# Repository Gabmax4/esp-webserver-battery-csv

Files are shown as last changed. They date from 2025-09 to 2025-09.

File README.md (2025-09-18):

# ESP Web Server — Battery Dashboard & 25-Bay Charger

An ESP8266/ESP32 project that exposes battery telemetry via an on-device **web server**, renders a **real-time chart** in the browser (AJAX), and lets you **export CSV** for analysis.  
The repo also contains the **hardware for a 25-slot charging dock** with per-slot **CHARGE/FULL** LEDs.

Frontend lives in **`data/index.html`** (SPIFFS/LittleFS). The page polls `/battery` periodically and updates the chart; CSV can be downloaded from the same page or from a dedicated endpoint.

---

## Why it matters (OT/IoT)
- Classic **edge → UI** pattern: local telemetry, simple control, CSV export.
- Demonstrates **HTTP endpoints**, **AJAX polling**, ADC-based battery measurement, and a browser dashboard suitable for SCADA/MES-style views.

---

## Architecture

```mermaid
flowchart LR
  S[Battery/Divider -> ADC] --> M[ESP8266/ESP32 WebServer]
  M --> UI[Dashboard]
  UI --> M
  M -.-> L[LED endpoints optional]
```

---

## Features
- On-device WebServer (firmware `.ino`).
- Real-time chart (AJAX + Highcharts) from **`data/index.html`**.
- Battery endpoints and optional LED control endpoints.
- CSV export from the UI or a dedicated `/export.csv` path.
- Runs entirely on LAN (no cloud dependency).

---

## Endpoints

| Method | Path | Content-Type | Purpose |
|---:|---|---|---|
| GET | `/battery` | `application/json` (or plain text) | Returns latest battery reading (`voltage`, `percent`). |
| GET | `/export.csv`  | `text/csv` | Streams `timestamp,voltage,percent` rows. |
| GET | `/ledverde?...`, `/ledamarillo?...`, `/ledrojo?...`, `/ledblanco?...` | `text/plain` | Optional RGB controls. |
| GET | `/ledfiesta?intensidadfiesta=…&delayfiesta=…` | `text/plain` | Optional “party” mode. |

The HTML polls `/battery` every ~1s and updates the chart.

---

## Repository layout (as used here)

```
/data                                  # SPIFFS/LittleFS content served by the ESP
  index.html
/Simulacion 3D                         # Schematics, PCBs, 3D previews
/Graficas bateria/Analis de las graficas
/Datasheets
/Documentos y proveedores
/Logos
/Pulseras PCB
ESP_Grafica_WebServer.ino              # main firmware (web server + endpoints)
Lectura_Bateria.ino                    # ADC helpers (voltage/percentage)
LICENSE                                # MIT
README.md
```

> Note the folder name for charts is **Analis de las graficas** (without the second “i”). Paths below use that exact spelling and URL-encoding for spaces.

---

## Hardware — Wearable board (ESP-12F)

- **MCU:** ESP-12F / ESP8266MOD (Wi‑Fi + ADC).  
- **Regulator:** AP2112K‑3.3 LDO (ESP powered from Li‑ion).  
- **RGB LEDs:** WS281x chain (e.g., WS2812/WS2813) on a single **Data** pin.  
- **Battery measurement:** resistor divider (e.g., **R7=402k / R8=100k**) with **C5=10µF** low-pass into **ADC**.  
- **Connector:** battery input + programming pads.

**Images**

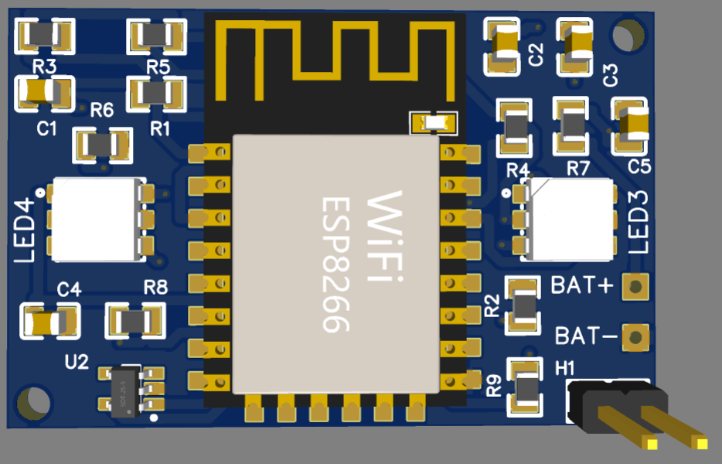
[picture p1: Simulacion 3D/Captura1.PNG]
ESP12 overview

Wearable schematic
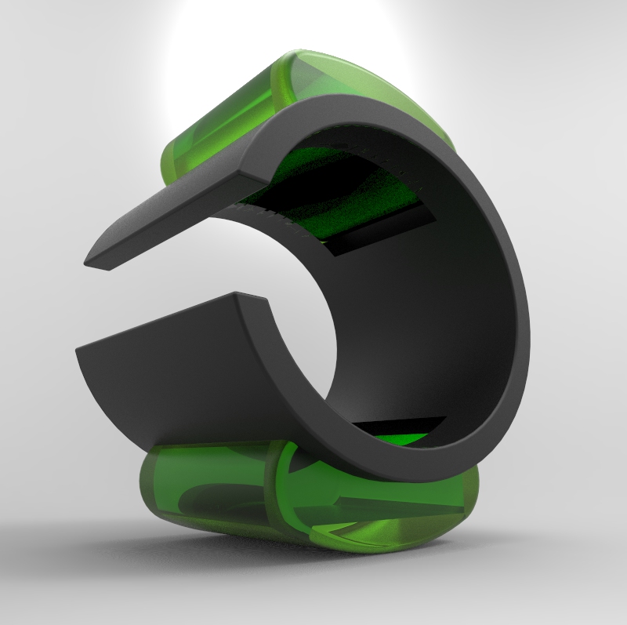
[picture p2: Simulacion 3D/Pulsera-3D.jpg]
Wearable 3D

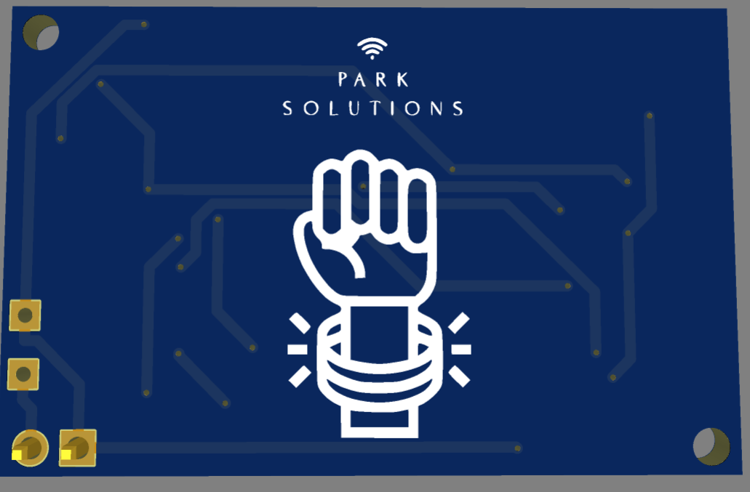
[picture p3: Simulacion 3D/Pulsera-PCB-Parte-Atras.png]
Wearable PCB back

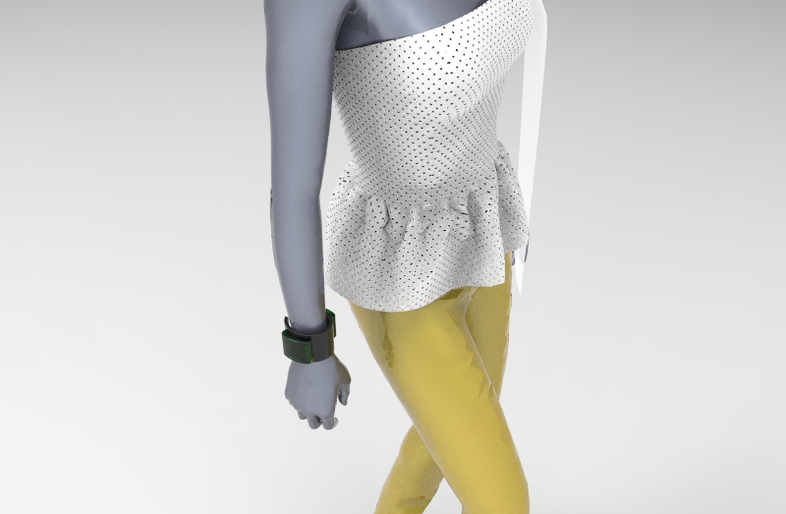
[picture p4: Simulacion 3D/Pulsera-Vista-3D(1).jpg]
3D view 1

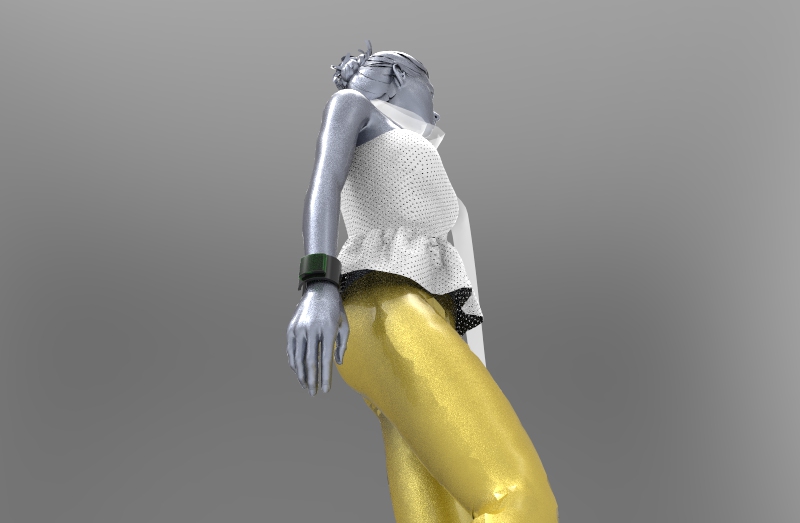
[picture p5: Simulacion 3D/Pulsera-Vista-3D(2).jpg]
3D view 2

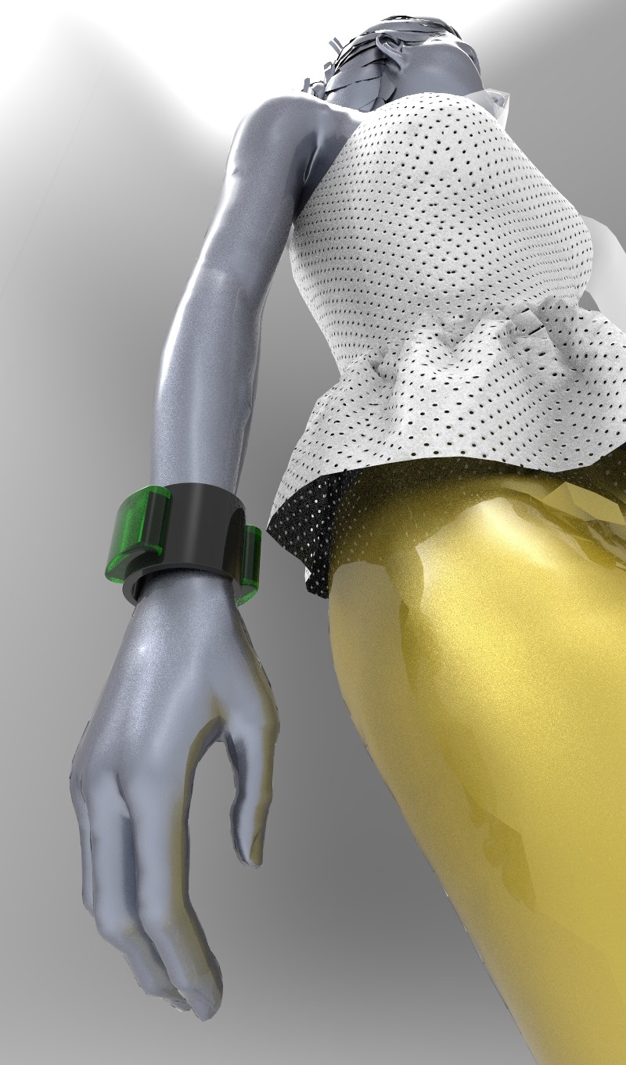
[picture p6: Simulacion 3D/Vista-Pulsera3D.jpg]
3D view 3


**Full project (schematics, PCB, BoM) on EasyEDA / OSHWLab:**  
- Wearable bracelet: https://oshwlab.com/gabmax4/pulsera-final

---

## Hardware — 25‑Bay Charging Dock

A multi‑slot charger that can **charge up to 25 bracelets simultaneously**, each slot with two status LEDs:
- **CHARGE** (charging in progress)  
- **FULL** (fully charged)

From the schematic notations, the design matches a **single‑cell Li-ion charger of the TP4056 class** (CC/CV) with a **DW01A‑class protection IC** and a **dual MOSFET pack** (e.g., FS8205A). These parts are commonly paired; if your exact IC markings differ, replace the names here with the precise part numbers from your PCB.

**Images**

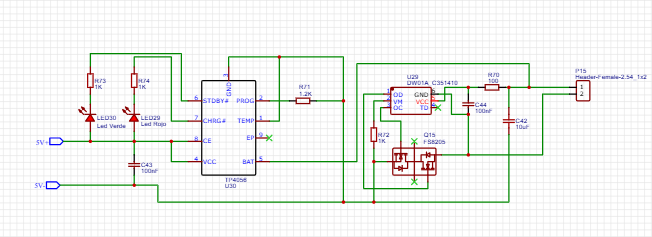
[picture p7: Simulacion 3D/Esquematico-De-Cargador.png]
Charger schematic

Charger board
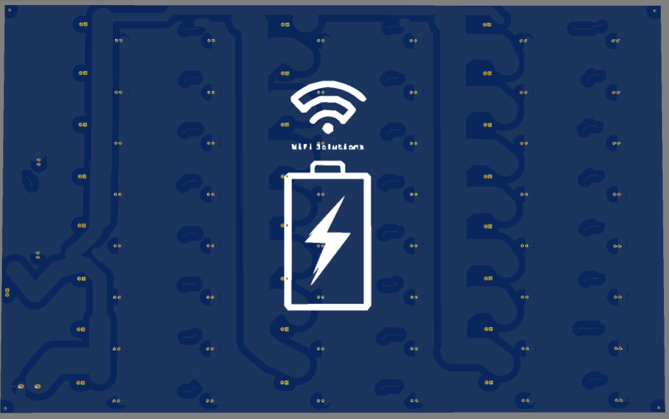
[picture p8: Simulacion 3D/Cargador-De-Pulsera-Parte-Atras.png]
Charger board back


**Full project (schematics, PCB, BoM) on EasyEDA / OSHWLab:**  
- Charger dock: https://oshwlab.com/gabmax4/cargador_pulseras

---

## Battery telemetry — Results & analysis

Live chart examples captured during testing:

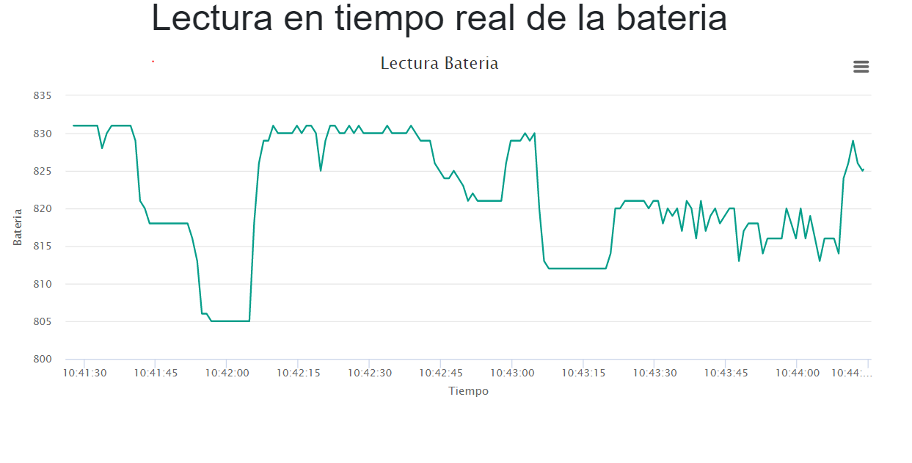
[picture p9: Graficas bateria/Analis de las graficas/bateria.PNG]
Battery live chart

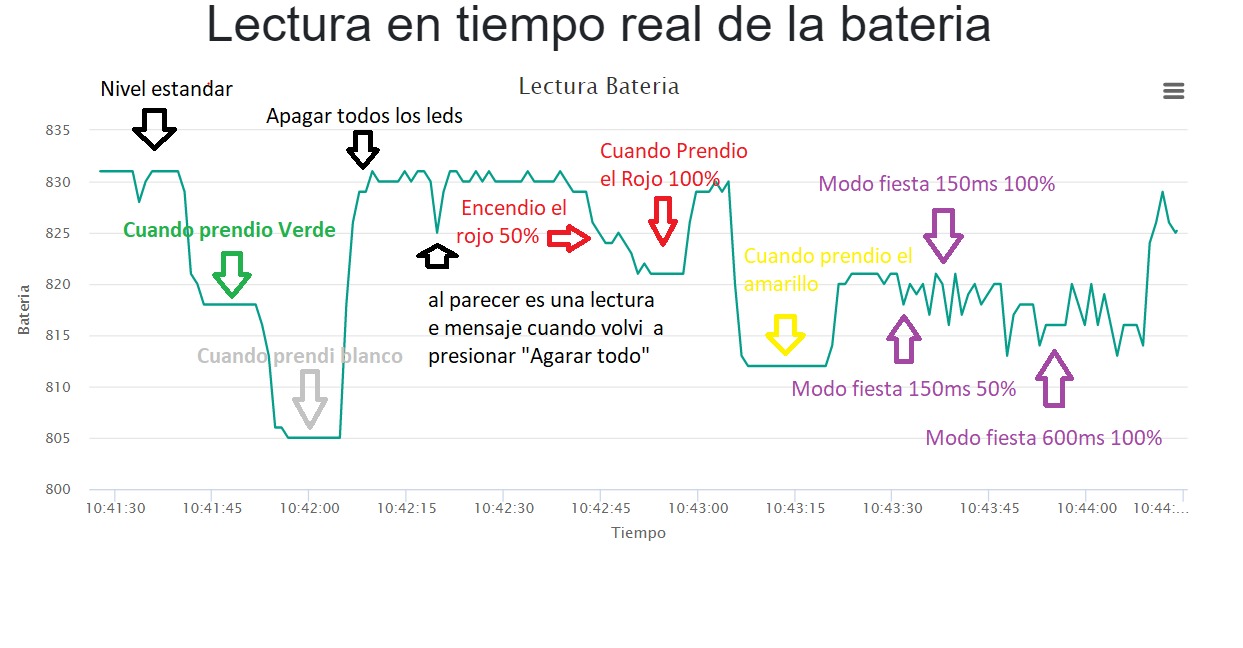
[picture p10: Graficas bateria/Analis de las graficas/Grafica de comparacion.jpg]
Annotated run


Related notes & PDF:
- Notes: `Graficas bateria/Analis de las graficas/Notas primera lectura sin grafica.txt`  
- PDF: `Graficas bateria/Analis de las graficas/lectura-bateria.pdf`

**Suggested metrics to report (fill in during a run)**
- Update latency (UI round-trip): `__ ms`  
- Dropped samples / packet loss: `__ %`  
- Voltage range & ADC scaling: `__ V` → `__ %`  
- CSV size: `__ rows` over `__ minutes`

---

## Build & upload

1. Configure Wi‑Fi in **`ESP_Grafica_WebServer.ino`**.  
2. Upload **SPIFFS/LittleFS** so **`data/index.html`** is available (Arduino/PlatformIO data upload tool).  
3. Flash the firmware.  
4. Open the device IP in a browser. The page polls **`/battery`** every ~1s and updates the chart.  
5. Download CSV from the page or via **`/export.csv`**.

---

## Security / production notes
- Add a **token/auth** if the device sits on a shared network.
- If hosting the dashboard off-device, restrict **CORS** to trusted origins.
- In OT networks, prefer network isolation/VLANs or VPN.

---

## License
Licensed under the **MIT License**. See [LICENSE](LICENSE).

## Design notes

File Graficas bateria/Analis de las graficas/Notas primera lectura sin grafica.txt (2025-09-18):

Valor lectura de la batería

ente 835 - 838 equivalieron a 4.02V midiendo mientras estaba en uso el chip!
el valor que dio cuando solo medimos la batería fue de 4.13V  sin conectarle el chip 

y los cálculos indican que como valor máximo se llega a una lectura de 875 que equivaliera aproximadamente 4.2V 
pero que este voltaje nunca es alcanzado realmente 

Ya hicimos pruebas y si se envía de manera correcta el valor de la batería

se estima que el valor de batería descargada 3.2V equivalga a 666

Con 835 equivale a 4.02V
y se midio la lectura con 4.38V  lo cual nos dio un valor analógico de 910 y eso indica que nuestras aproximaciones son correctas

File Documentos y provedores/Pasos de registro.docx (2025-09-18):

1. Llega el morro o papa y se registra
2. Se guarda en la base de datos
3. SOY SET!
4. BUSCAR SET
5. SE SELECCIONA
6. SELECCION PULSERA #X
7. MANDAR ALA PULSERA #X ESTATUS_BAT=1
8. PULSERA RESPONDE CON CARGA DE BATERIA BATTERY=%Y Y PULSERA SE EN ESPERA
9. LED=VERDE!
10. ESTATUS_LED=YA ME PRENDI WE!
11. PROCESO ALTERNO LA PULSERA LLEGA A PRENDER ROJO
12. DEVULEVEN LA PULSERA Y NOS MANDAN LED=OFF

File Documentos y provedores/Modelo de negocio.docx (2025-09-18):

Modelo de negocio

Segmento de mercado

Nuestro segmento estará dividido en dos vertientes

Niños

De entre 5 y 14 años de edad cuyos padres estén dispuestos a pagar por su diversión y entretenimiento-recreacion

Jóvenes

De entre 16 y 25 años, Cuyos padres o ellos mismos estén dispuestos a pagar por el servicio de diversión que ofreceremos el cual ningún parque de este tipo esta ofertando.

Propuesta de valor

Tres propuestas de valor son las que harán la diferencia en el lugar que las desarrollemos.

Eco parque

Un parque que no dependa de la energía suministrada por CFE, es decir el parque generara su propia energía eléctrica suficiente para suministrar la iluminación, audio, computadoras, refrigeración, etc. ¿De qué manera? a través de los saltos en los trampolines es como nosotros convertiremos ese movimiento/fuerza en energía eléctrica.

Ahorrar en energía eléctrica genera un impacto altamente efectivo y más si esa energía es generada por los mismos clientes quienes además de pagar por el uso del parque, pagan por generar la energía que este utilizamos.

Automatización

Los sistemas de control, ingresos de clientes, conteo de tiempo etc.… Incluso inventarios no tienen por qué seguir siendo análogos, ni generar una carga de trabajo y mucho menos personal innecesario.

A través de una combinación de elementos de software, crearemos una plataforma capaz de controlar el ingreso de los clientes y el tiempo que tienen para disfrutar del parque al punto de que no tenemos que revisar bitácoras sino que el mismo sistema indicara cuando el tiempo se agote así mismo el cliente se dará cuenta pues llevara una pulsera que se iluminara de cierto color cuando el tiempo este agotado, además de contar con pantallas que indicaran el tiempo que tiene cada persona, esta pulsera también servirá para acumular puntos, realizar compras y tener beneficios como, promociones, fila preferencial premios etc.. Además también se contara con una aplicación móvil en la cual se puede realizar la compra del tempo con anticipación evitar llegar a hacer fila para pagar.

Juegos e interacción virtual/física

Sabemos que es difícil que un niño hoy día salga y haga actividad física, pues este será el lugar indicado, ya que desarrollaremos Juegos que incluyan la actividad física y la implementación virtual

Todos los parques ofrecen un servicio similar trampolines), sin embargo esto hará la diferencia y atraerá más clientes además de mantener a los que tenemos y generar publicidad de boca en boca, pues sabemos que la atracción que ofreceremos será una experiencia única!

Canales de distribución

(Estrategia de introducción)

Nuestros canales de distribución con el cliente final serán de manera digital, generar un público meta y desarrollar campañas en facebook y youtube donde a través de un video publicitario mostraremos las atracciones que ofrece el parque, precios, promociones, etc.

Negociar con algunos negocios clave para que reproduzcan el video cierta cantidad de veces por cierto tiempo en sus pantallas.

Relaciones con los clientes

La relación que tendrá el personal del parque con los clientes del parque buscamos que sea de autoservicio, esta relación combina una forma más sofisticada de autoservicio con procesos automáticos.

Donde el cliente pueda apartar su lugar o realizar su compra desde antes y pagar para solamente llegar checar y comenzar a hacer uso del parque

Fuente de ingresos

La principal fuente de ingresos es la cuota por uso, es decir lo que el cliente paga por usar el parque.

¿Por que estarán dispuestos a pagar por este valor?

En primera instancia, se contara con una app donde el cliente podrá realizar su registro y comprar su tiempo anticipadamente y pagarlo.

Podrá apartar el lugar para eventos desde la app sin necesidad de ir o llamar.

No solo se contara con los trampolines, sino que dentro del parque se tendrán Juegos interactivos que combinen el uso de los trampolines y el entretenimiento virtual.

Recursos clave

Nuestros recursos importantes son todos los componentes que se utilizaran para la instalación y la puesta en marcha del sistema de generación eléctrica así como la implementación del sistema controlador.

Para la gestión de venta y juegos, nuestros recursos serán los servidores y nuestro software el cual será el punto más importante y donde más daremos peso para que funcione a la perfecciona si como la app que se desarrollara y vinculara con este sistema.

Actividades clave

Generación de energía

Atreves de los saltos en trampolines estratégicos colocaremos un mecanismo, el cual con el salto del trampolín lo convertirá en movimiento lineal para que este a través de un generador, convertirá ese movimiento en energía misma que se llevara a un inversor y después a los bancos de baterías, para que llegue a la red de CFE y suministre nuestra energía, esto claro con los parámetros establecidos por la comisión.

Punto de venta

Un punto de venta desarrollado por nosotros, el cual el cliente tendrá como control su propia pulsera la cual servirá para entrar al parque y tener el conteo de su tiempo, puntos, promociones, compras etc. partiendo de esta manera:

El cliente tendrá dos maneras de comprar tiempo para uso del parque, el podrá pagar el tiempo que desea desde la aplicación, si es un cliente nuevo, deberá realizar su registro en la aplicación y el pago, para después solo pasar al modulo de prepago a recoger la pulsera, si no lo hace a través de la aplicación, deberá llegar al modulo de registro y pago, donde se le solicitaran los datos de la persona que usara el parque: nombre, edad, domicilio del padre, aceptación de términos y condiciones.

La pulsera el cliente tendrá que devolverla al término de su tiempo esto será a la hora de su salida,

En caso de que realice el pago en línea podrá llegar, solicitar su pulsera y entrar en automático al parque solo colocando su pulsera en el lector RF-ID, el cliente puede colocar saldo a favor en su pulsera para que pueda realizar compras dentro del parque. como se manejara el tiempo? en el momento en que el cliente coloque su pulsera en el lector el tiempo comienza a correr, el cual será mostrado en las pantallas y su pulsera se iluminara de color verde mientras este dentro de su tiempo, cuando el tiempo se le termine la pulsera encenderá una luz roja indicando la finalización, así mismo esta estará vinculada al servidor el cual realizara el registro en computadora de que el tiempo ya se termino. Tmbien será mostrado en las pantallas del lugar

Por medio de la aplicación se podrá apartar el área de fiestas detallando la cantidad de personas, nombres, edades y tiempo para poder tener listas las pulseras de los que entraran al parque

El punto de venta tendrá ventajas muy variadas tales como, corte de caja, control de inventario, control de tiempos, control de empleados….

Juegos

Se instalara en dos de los trampolines grandes que están frente a la pared, dos sensores de movimiento y dos proyectores , los cuales seran para proyectar dos juegos diferentes, uno constara en tener que realizar saltos grandes para ir escalando obstáculos y recoger monedas para llegar hasta lo mas alto o lejos posible , quien llegue a lo más alto o recoja mas monedas se le generaran puntos en su usuario los cuales podrá cambiar por tiempo o productos, otro de los juegos consistirá en ir esquivando obstáculos con los brincos y tomar objetos valiosos que de igual manera el que llegue más lejos y consiga mas objetos generara puntos y beneficios

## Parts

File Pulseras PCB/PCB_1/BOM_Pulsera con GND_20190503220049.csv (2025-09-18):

ID | Name | Designator | Footprint | Quantity | Manufacturer Part | Manufacturer | Supplier | Supplier Part | LCSC Assembly | LCSC
1 | 16MHz | X1,X2 | HC-49SMD | 2 | X49SSM16MSD2SI | YXC | LCSC | C96138
2 | 22pF | C5,C6,C7,C1 | 0402' | 4 | 0402CG220J500NT | FH | LCSC | C1555 | Yes
3 | 2.2nF | C2 | 0402' | 1 | 0402B222K500NT | FH | LCSC | C1531 | Yes
4 | 4.7pF | C3 | 0402' | 1 | GJM1555C1H4R7CB01D | MuRata | LCSC | C85883
5 | 1.5pF | C4 | 0402' | 1 | GJM1555C1H1R5BB01D | MuRata | LCSC | C76900
6 | 1pF | C8 | 0402' | 1 | GJM1555C1H1R0BB01D | MuRata | LCSC | C76898
7 | 33nF | C9 | 0402' | 1 | GRM155R71E333KA88D | MuRata | LCSC | C77016
8 | 1nF | C10 | 0402' | 1 | CL05B102KB5NNNC | SAMSUNG | LCSC | C14442
9 | 10nF | C11 | 0402' | 1 | GRM155R71H103KA88D | MuRata | LCSC | C77019
10 | 8.2nH | L1 | 0402' | 1 | SDCL1005C8N2JTDF | Sunlord | LCSC | C16208 | Yes
11 | 2.7nH | L2 | 0402' | 1 | SDCL1005C2N7STDF | Sunlord | LCSC | C27123 | Yes
12 | 3.9nH | L3 | 0402' | 1 | SDCL1005C3N9STDF | Sunlord | LCSC | C14033 | Yes
13 | 1MΩ | R1 | 0402' | 1 | RC0402FR-071ML | Yageo | Mouser | 603-RC0402FR-071ML | Yes | C25879
14 | 22K | R2 | 0402' | 1 | 0402WGJ0223TCE | UniOhm | LCSC | C25547
15 | nRF24L01-REEL | U3 | QFN-20_4X4X05P | 1 | nRF24L01-REEL | NORDIC | LCSC | C93664
16 | 10K | R3,R4 | 0402' | 2 | 0402WGJ0103TCE | UniOhm | LCSC | C25531
17 | 10uF | C12 | SMD,4X5.4MM | 1 | EEE1EA100WR | PANASONIC | LCSC | C178501
18 | 100nF | C13 | 0402' | 1 | GRM155R61C104KA88D | MuRata | LCSC | C77005
19 | SMD 5050 RGB (B-R-G) | L4 | SMD 5050 RGB | 1 | SMD 5050 RGB
20 | ATMEGA8L-8AU | U2 | TQFP-32_7X7X08P | 1 | ATMEGA8L-8AU | MICROCHIP | LCSC | C9755
21 | 1N4004W | D1,D2 | DIODE_SOD-123FL | 2 | 1N4004W | Jingdao | LCSC | C162734 | Yes
22 | Header-Male-2.54_1x1 | BAT+,BAT-,VCC-FTDA,DTR,RX,TX,GND-FTDA | HDR-1X1/2.54 | 7 | Header-Male-2.54_1x1 | ReliaPro | LCSC | C81276
23 | WiFi Antena | A1 | WIFI ANTENA | 1 | New SchematicLib

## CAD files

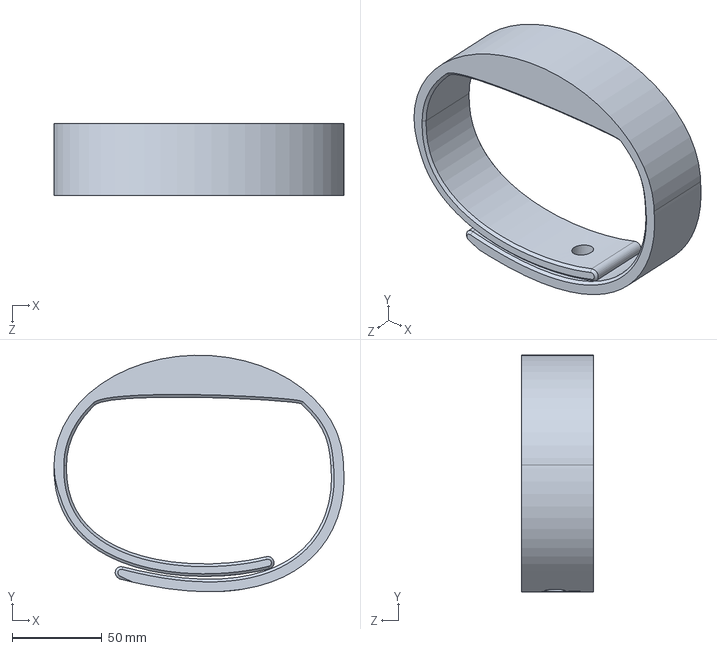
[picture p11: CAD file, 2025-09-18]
Pulseras PCB/Pulcera 1.SLDPRT
161.7 x 131.9 x 40.0 mm

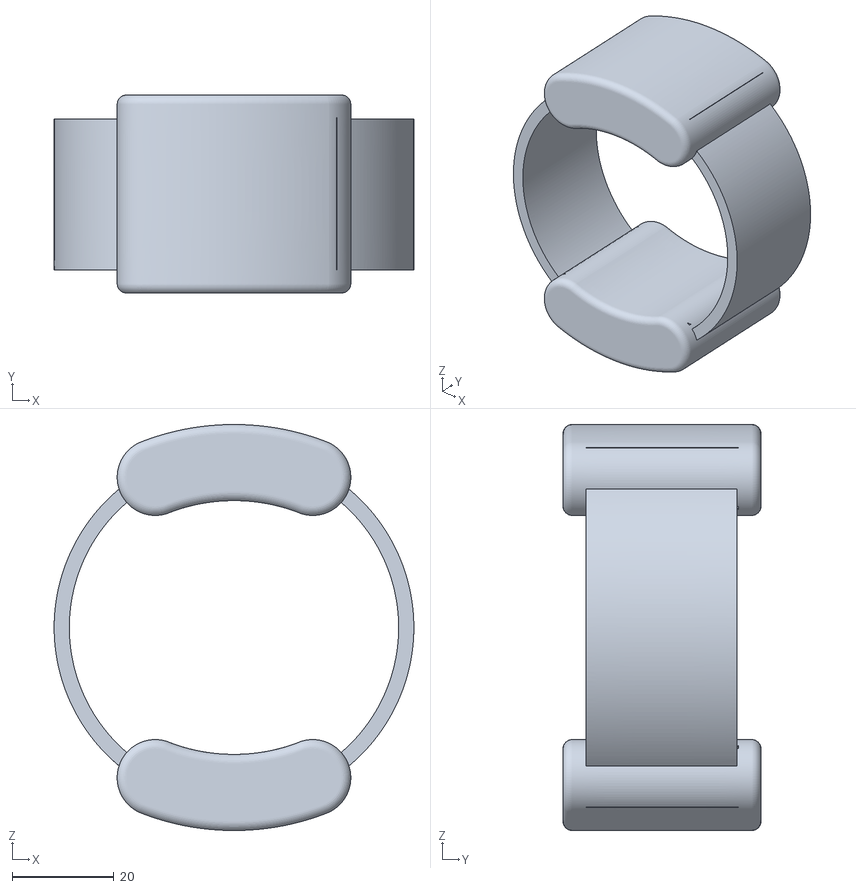
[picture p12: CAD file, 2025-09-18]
Simulacion 3D/Pulsera-3D.stl
70.9 x 39.0 x 80.0

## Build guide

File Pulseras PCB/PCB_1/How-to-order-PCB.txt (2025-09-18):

How to Order PCB

Please refer to:
https://docs.easyeda.com/en/PCB/Order-PCB

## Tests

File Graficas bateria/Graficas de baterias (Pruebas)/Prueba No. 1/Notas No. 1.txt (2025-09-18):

Esta Prueba fue grafica echa con los led blancos a 255

-Al principio de la prueba empezo a un nivel normal empezo a un nivel de 766 unidades La bateria no estaba totalmente cargad
asi que no se puede definir este como el nivel maximo de carga

-despues encendi los leds y al parecer la bateria o la pulsera tiene una ligero corto o mal funcionamiento esto lo note
por que al mover un cable tal vez hizo corto y empezo a funcionar mal devido a esto vi como el consumo de la bateria era exesivo
y se vio una caido muy intensa cuando prendi los led bloncos a maxima potencia 

*al parecer el nivel de minimo funionamiento cuando empezo a solo prender el rojo y dejo de prenderse blanco fue a un valor cercano
a los 610 unidades

-volvi a conectar la pulsera y parecia ser que todo marchaba bien asi que volivi a encender los led blancos a maxima intensidad 
justo a las 12:00 y me dio una lectura de 712 unidades al cabo de 15 minutos 12:15 la medicion fue 705.

12:00 - 712 
12:15 - 705
12:30 - 697
12:45 - 689
13:00 - 680
13:15 - 673
13:30 - 665
13:45 - 658
14:00 - 654
14:11 - 652

7-8-8-9-7-8-7-4 *2   EStos numeros son la diferencia que hay entre cada medida como se puede obrevar los que mas se repiten 
es el 8 y el 7 el 2 es una medida que no entro dentoro del estandar de 15 min si se divide 8 o 7 unidades por los 15 minutos
nos da que por cada minuto que pasa se consumenen entre 0.533 y 0.466 unidades 

entonces si 712 es la medida del 100% y 610 0% la diferencia de unidades entre los dos son 102
si cada munito equivale a 0.533 o 0.466 y dividimos 102/0.533 o 102/0.466
se estima que la pulsera dure  ente 3h con 12min y 3h con 38min 

claro teniendo en cuenta que la grafica es lineal 

prueba echa el 16/11/2020

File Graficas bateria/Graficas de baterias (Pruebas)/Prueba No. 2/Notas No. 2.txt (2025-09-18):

Esta prueba fue echa con los led blancos a 255

Estas lecturas fueron hechas mientras pasaba algo raro con la bateria ya que el cargador el cual
utilice prendian los dos focos envez de prender solo uno y a revisar note que se quedo en un valor
alrededor de 3.6V lo cual vi como un problema ya que no pasaba de esa brecha pero corri la prueba con ese voltaje 
y obtuve que cuando lo conecte bajo el voltaje de 3.6V a 3.1V y en la grafica nos daba un valor de 645 unidades 
segun los resultados de las "Notas primera lectura sin graficar" deduje que

835 = 4.02V
875 = 4.20V
910 = 4.38V
666 = 3.20V   //Estimado con el cual ya no deberia de funcionar el sistema 

COMPARACION DE RESULTADOS CON LOS PRIMEROS RESULTADOS LEIDO EN LAS PRUEBAS

En esta ocacion obtuve estas lecturas al medir con el multimetro y ver la grafica 

645 = 3.1V
606 = 2.9V

teniendo en cuenta esto confirmaremos que los calculos de "Notas primera lectura sin graficar" sean correctas solo para validar

si 			835 = 4.02V
entonces cuanto es...	645 = ?			hacemos una regla de 3 y nos da que

			645 = 3.1052V		exactamente la medida que medimos con el multimetro

confirmacion #2 

			835 = 4.02V
			606 = ?

			606 = 2.9175V		medicion casi exacta que la que medimos que fue 2.90V
al ver que todo esta correcto podemos confiar en las mediciones de unidades desconocidas a unidades de voltaje 
en futuras notas

MEDICIONES OBTENIDAS DE LA GRAFICA

me espere unos minutos para poder prender los led a maxima potencia me espera a que fueran las 4:15 para que empezara acorde con las 
mediciones de cada 15 min, la medicion que daba sin prender los led era 649 = 3.12V (aproximados/no medidos calculados) mediciones 
obtenidas:

4:15 = 610 = 2.93V
4:30 = 566 = 2.72V

solo duro prendido la luz blanca durante 19 min por lo cual solo tenemos una comparacion y como vemos esta diferencia es mayo 
que la medida en "Notas No.1" la cual era alrededor de 7 o 8 unidades en este caso son 44 unidades lo cual equivale a 0.21V la
cual es la diferencia que vemos entre  2.93V y 2.72V

cada unidad de equivale a 0.0048V esa es la presision de nuestra lectura tambien o 4.8uV (micro volts)
 
NOTA IMPORTANTE: como se estimo con anterioridad parace ser que la medida de 3.2v era lo menos con que podia funcionar la pulsera
estaba erroneo puesto que hoy confirmamos que pudo funcionar con la luz blanca prendida hasta aproximadamente valores cercanos a
550 y 555 unidades (puede ser una opcion que no halla distingido entre un 100% de intensidad pero a mi perspectiva se veia bien e
intenso como si fuera el 100%) depues de este numero medido que en voltaje equivale entre 2.64V y 2.67V. Cuando llego a el valor de 
543 = 2.61V dejo de mandar datos a la grafica se encendio los led rojos pero con muy baja intensidad duraron unos minutos y se apago
al ver que no prendia hice una ultima medicion con el multimetro y logre captar 1.68V aproximadamente 

estas notas y pruebas fueron echas el 17/11/2020

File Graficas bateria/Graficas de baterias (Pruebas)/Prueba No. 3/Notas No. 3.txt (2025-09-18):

Esta prueba fue corrida con los leds blancos a 255

empezamos la prueba con un valor de 3.72V sin conectar la pulsera una vez conecte la pulsera obtuve un valor de 3.49V depues prendi los 
leds blancos y volvi a medir y note que bajo a un valor de haste 3.26V en esta prueba al cabo de 30min se me apago la computadora y tube
que dar esta prueba como un fracaso y volverla a intentar un punto que vi fue que cuando estaba en el valor de 3.0V o 2.99 que medi con el
multimetro decidi desconectarlo y vi como el voltaje aumento a 3.44V

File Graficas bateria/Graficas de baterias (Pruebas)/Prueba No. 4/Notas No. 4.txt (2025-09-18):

Esta prueba fue echa con los led blancos a 255

Antes de conectar la bateria a la pulsera leei con el multimetro 3.70V y cunado lo conecte vi que bajo a 3.49V pero 
todabia no mandaba señal a la computadora, al momento que empece a mandar datos volvi a hacer una medicion y vi que el voltaje
seguia siendo 3.49V. Cuando prendi el led blanco el voltaje bajo hasta 3.28V osea que las diferencias se voltaje fue

-CALCULOS DE PORCENTAJES

Cuando conecte la bateria 0.21V respecto a 3.70V
Cuando prendi el led fue de 0.42 respecto a 3.7V
y respecto a 3.49 bajo 0.21V

si tomamos en cuenta que 4.2V es el 100%
y 0V el 0% tenemos que
0.21V es el 5% y 0.42V 10%

pero si tomamos 4.2V como el 100% 
y 3V como el 0% nos da que 
0.21V es el 17.5% y 0.42V 35%
del porcentaje de la bateria

pero si ponemos el valor cuando dejo de mandar datos respecto a "Notas No. 2" veremos que
si 4.2V es el 100%
y 2.61V es el 0% tenemos que 
0.21V es el 13.2% y 0.42V es 26.4%

al inicio de la prubea se tenia una memdida de 729 unidades sin prender la luz blanca 
729 = 3.50V
cuando se encendieron los led blancos bajo a 
682 = 3.28V

-MEDICIONES DE CADA 15MIN

a continuacion las lecturas de cada 15 min

3:55 = 682 = 3.28V
4:20 = 672 = 3.23V
4:35 = 663 = 3.19V
4:50 = 662 = 3.18V
5:05 = 658 = 3.16V
5:20 = 654 = 3.14V

10-9-1-4-4 diferencias entre mediciones 

empezando desde las 5:25 (Que es igual a un valor entre 652 y 649 que son aproxiamdamente entre ) emezo a haber fluctuaciones entre 28 
y  hasta 90 unidades

5:35 = aproximado 630 = 3.03V
5:50 = aproximado 618 = 2.97V
6:05 = aproximado 601 = 2.89V
6:20 = aproximado 596 = 2.86V
6:35 = aproximado 592 = 2.85V
6:50 = aproximado 596 = 2.86V
7:05 = aproximad0 601 = 2.89V
7:20 = aproximado 585 = 2.81V
7:35 = aproximado 576 = 2.77V
7:50 = aproximado 575 = 2.76V
8:05 = aproximado 570 = 2.74V
8:20 = aproximado 530 = 2.55V
8:30 = aproximado 512 = 2.46V     (ultima medicion)

12-17-5-4-(-4)-(-5)-16-9-1-5-40-18  Difrencia entre mediciones

el valor mas bajo medido fue 498 = 2.39V a la hora de 8:15:33

-CONCLUSIONES			

en esta grafica como vemos la grafica no parece ser lineal como en el caso de la grafia de las "Notas No. 1" donde teniamos claro
que proximadamente se bajaban entre 7 y 8 unidades por cada 15 minutos al ver esta grafica no parece ser linetal y esto puede ser
devido a que la bateria ya esta cada vez mas estropeada lo cual hace que no sea algo linea, esta vez obtuvimos una medicion aun
menor que las tomadas en las "Notas No. 2" que fue de 543 = 2.61V esta vez obtuvimos un valor de 498 = 3.39V pero cuando dio este
valor no se apago solo fue el valor minimo leido se apago al dar la lectura de 512 = 2.46V lo cual nos dice que el margen de menor
rango de uso esta entre 543 y 498 unidades. el proyecto duro andando desde las 03:50:23 hasta las 08:30:35 esto nos da que la pulsera
estuvo en funcionamiento durante 6:20:58 (6h 20min y 58seg) esto con los led blancos prendidos antes de eso estuvo prendido durante 
5min con 21seg eso nos da en total un funcionamiento de 6h 26min y 19seg. Esto es mas de lo que se anteriormente se estimo

23/11/2020

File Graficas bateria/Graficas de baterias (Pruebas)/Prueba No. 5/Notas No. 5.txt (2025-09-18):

Esta prrueba fue corrida con el led amarillo a 255 

En "Notas No. 4" se dice que el voltaje leido sin que se conectara la bateria a la pulsera fue de 3.70V y cuando se conecto bajo a 
3.49V. En esta caso la batieria sin conectar a la pulsera dio 3.97V y conectado a la pulsera dio 3.64 tambien cuando estaba mandando
datos dio una medicion de 3.64V. a diferencias que lo que se mostro en las "Notas No. 4" se vio que el bajon de voltaje cuando se conecto
fue de 0.21V y en este caso fue de 0.33V osea que en este caso todavia bajo mucho mas que la ultima vez que se conecto la pulsera 

---------------------------CALCULOS DE CUANTO SE SUPONIDA QUE DURARIA ESTA PRUEBA CON EL AMARILLO-----------------------------------------

coomo se puede ver en la prueba pasada la bateria estaba mas cargada que esta vez a conitinuacion se muestran los calculos para saber que
tanto estaba cargada de mas respecto a la medicion anterior.

supongamos que 3.7V es el 100% para que el sobrante de 100% sea la comparativa entonces

3.70V = 100%
3.97V = ?

(3.97V)(100%)/3.70V = 107.30% redondiando 100% - 107.30% = 7.30%

ahora se hara lo mismo pero con los valores cuando se conecto la pulsera

3.49V = 100%
3.64V = ?
(3.64V)(100%)/3.49V = 104.30% redondiando 100% -104.30% = 4.30%

tomare como medida de cuanto estaba mas cargada respecto a la ultima prueba la de 4.30% por que esta medida fue realizada ya que se
conecto la bateria a la pulsera asi que se me hace una medida mas real. Ahroa como vimos en la "Pueba No. 4" duro un tiempo de 
6h 20min y 58seg para sumarle el 4.30% que nos falta tomaremos la primera parte que se ve lineal de la grafica que pueron los primeros
30min a 15min los cuales tuvieron una caida de entre 9 y 10 unidades por lo cual:

si cada 10 unidades = 15min 

ahora tenemos que determinar ese 4.30% a cuanto es equivalente yasea en unidades o en voltaje
entonces si 3.70V = 100%
	      ?   = 4.30% 

(4.30%)(3.70V)/100% = 0.1591V

ahora que sabemos el voltaje equivalente a 4.30% lo convertimos en unidades si sabemos que 
que 1 unidad = 0.0048V
	 ?   = 0.1591

(0.1591V)(1 unidades)/0.0048V = 33unidades
y estas 33 unidades en tiempo queremos saber cuando equivale por lo cual hacemos la sigueinte regla de tres

10 unidades = 15min
33 unidades = ?

(33 unidades)(15min)/10 unidades = 49min con 30seg 

------------------------------------CALCULO DE APROXIMACION DE TIEMPO ENCENDIDO DE PRUEBA NO.5-------------------------------------------

entonces suponiendo que la pila estuviera 4.30% mas cargada duraria  en cuestion aproximadamente 7h 10min y 28seg y al ver el "Grafico 
prueba" vemos que el led amarillo es aproximandamente un 75% de lo equivale el led blanco entonces hay que sumar el 25% restante para
poder hacer un aproximado de lo que durara el led amarillo y si esto es cierto podriamos llevar este calculo a las demas graficas 
para saber un aproximado de cuanto nos dara. Entonces

transformaremos todo el tiempo en segundos 
25828 seg = 100% 
    ?     = 25%
(25%)(25828seg)/100% = 6457 seg
esto es 1h 47min y 37seg claro esto es tomando en cuenta de que nuestro sistema sea lineal pero no lo es por lo cual el valor sera 
inferior a esto pero podemos darnos una proximado con estos numero. Entonces podemos aproximar que esta prueba va a durar
8h 58min 5seg

----------------------------------------------VALORES PRACTICOS---------------------------------------------------------------------------

La prueba con los leds amarillos prendidos a 255 duro 7h 12min y 58 seg y antes de prender el led amarillo dure 5min antes de prenderlo 
eso son deje que mis calculos tuvieron maregen de error de:
32285seg = 100%
25978seg = ?

(25978seg)(100%)/32285seg = 80%

ahora hacer las mediciones que se obtivieron cada 15min en la prueba:

4:00  = 710 = 3.41V
4:15  = 705 = 3.39V  (bajada extraña)
4:30  = 694 = 3.33V
4:45  = 691 = 3.32V
5:00  = 684 = 3.29V
5:15  = 680 = 3.27V
5:30  = 673 = 3.24V
5:45  = 667 = 3.21V
6:00  = 662 = 3.18V
6:15  = 655 = 3.15V
6:30  = 652 = 3.13V
6:45  = 648 = 3.11V
7:00  = 645 = 3.10V
7:15  = 643 = 3.09V
7:30  = 642 = 3.09V
7:45  = 640 = 3.08V
8:00  = 640 = 3.08V
8:15  = 639 = 3.07V
8:30  = 637 = 3.06V
8:45  = 633 = 3.04V
9:00  = 630 = 3.03V
9:15  = 628 = 3.02V
9:30  = 626 = 3.01V
9:45  = 622 = 2.99V
10:00 = 618 = 2.97V
10:15 = 615 = 2.96V
10:30 = 609 = 2.93V
10:45 = 604 = 2.90V                     (desde este punto callo como tipo exponecial mente)
11:00 = 590 = 2.84V
11:12 = 560 = 2.69V                     (ultima medicion)

5-11-3-7-4-7-6-5-7-3-4-3-2-1-2-0-1-2-4-3-2-2-4-4-3-6-5-14-30
los valores que mas se repitieron fueron 3-4-2 aproximadamente este valor equivale a 0.01V que como vemos es el valor que mas se repite
asiq ue podemos definir que cada 15 min se restaban 0.01V aproximadamente

En otras ocaciones como en caso de la prueba 4 y 2 dieron valores de desactivacion sercanos 512 y 543 en esta ocacion fue 560 el cual a
sido el valor mas alto de desactivacion que se a registrado 

NOTA: una vez que ya no mando datos instantanea mente se prendio la luz como un tipo de naranja esto se debe a que ya no fue suficiente
la energia para prende amarillo por cual las luces disminuieron su potencia y se vio un tipo de naranja supongo por que el led verde ya 
no tenia suficiente ptencia y bajo su intensisdad ya que el amarillo es una combinacion del rojo y verde y normalmente el rojo es el que
se queda prendido puesto que es el que menor cantidad de energia consume. Esto quiere decir que aun tenia mas energia que entregar pero
por alguna razon ya no pudo entablar comunicacion y mandar datos cuando esto ocurrio rapidamente hice una medicion con el multimetro
y medio valores entre 2.29V y 2.27V. ALGO IMPORTANTE fue que cuando desconecte la bateria volvi a medir con el multimetro y me dio 
entre 2.94V y 2.99V en el multimetro lo que se recomienda como el minimo de la bateria.

----------------------------------------------------------CONCLUSIONES--------------------------------------------------------------------

Al ver la grafica parece ser lineal de menos en los primeros momentos y podemos ver como justo cuando se desnecto se vio una bajada
muy pronunciada de voltaje por lo cual podemos definir ese punto como el limite de la grafica veremos en sigueintes pruebas si este 
punto es igual a los que se leeran futuramente, este punto fue aproximadamente en el 600, lo que se abia definido antes es que este 
no baje la pila del valor de 3V el cual aproximadamente equivale a 625 unidades que para que llegara a este punto en la grafica duro 
5h con 35min lo cual se me hace mas que suficiente para las demandas del proyecto. 

24/11/2020

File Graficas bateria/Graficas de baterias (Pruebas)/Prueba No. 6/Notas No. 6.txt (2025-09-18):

Esta prueba fue corrida con el led verde a 255 

A diferencia de otras pruebas en esta realice mediciones de volaje cad 15min para poder checar si mis reglas de 3 y mis calculos son
correctos. Este fue el primer caso que tue que el cargador me cargo totalmente mi bateria pero al parecer no me lo cargo totalmente
puesto que el voltaje no llego a los esperados 4.2V si no que cuando lo medi sin conectarlo a la pulsera me dio un valor de 
4.01V y cuando lo conecte a la pulsera bajo a un valor de 3.87V esto causo una caida de voltaje de 0.14V, tambien realice la lectura 
cuando estba mandando datos y fue exactamente igual que cuando se conecto la bateria a la pulsera 3.87V a continuacion analizare 
las caidas de voltaje de las anteriores pruebas para ver si existe alguna realcion y siempre es la misma.

"Notas No. 2"
3.60V a 3.10V difrencia = 0.50V

"Notas No. 3"
3.72V a 3.49V difrencia = 0.23V

"Notas No. 4"
3.70V a 3.49 difrencia = 0.21

"Notas No. 5" 
3.97V a 3.64V difrencia = 0.33

"Notas No. 6" (son estas)
4.01V a 3.87V difrencia = 0.14

todas los resultados anteriores fueron sin prender ningun led solo conectando la pulsera, creo que esto debe a que la bateria tiene una 
resistencia interna por lo cual el voltaje se ve implicado y es un poco diferente a medida que el voltaje de la fuente es diferente
puesto que esta resstencia interna tiene que mandar mas corriente o voltaje pero como vemos en el caso de Notas No.2 y No.3 el valor es 
muy parecido solo vayo por 0.02V, esto me hace que mi hipotesis que esto es por una resistencia interna sea la mas cercana a este caso
puesto que a medida que es un valor mas grande el voltaje que se quita de la fuente (bateria) es menor y a medida que es mas bajo este 
valor y corro la prueba veo que hay mas caida de voltaje por lo cual he llegado a la conclusion que entre mas cargada este la bateria
mas tiempo de vida tendra puesto que habra una descarga mas progresiva ESTO ES IMPORTANTE! Tratare de hacer pruebas con siempre el 100%
de carga segun mi cargador que al parecer ronda de los 4V hacia arriva para ver si existe alguna coinsidensia.

-------------------------------------MEDICIONES HECAS CON EL MULTIMETRO-----------------------------------------------------------------

A continuacion en esta prueba a diferencia de las otras realice mediciones con el multimetro aproximadamente cada 15min para de ese modo
ver si nuestros calculos de lo que equivale las unidades de la bateria estan bien con el valor de voltaje que creemos que nos da y si hay
un error tratar de corregir las medidas para ajustarlo y tener mas presision. A continuacion muestro mis mediciones echas con el multimetro
y cuando me marco la grafica cuando la volvi a revisar en el punto que segun yo hice la medicion por que claro puede tener margen de error

3.77V = 787 unidades = 11:15
3.73V = 778 unidades = 11:30
3.70V = 773 unidades = 11:45
3.67V = 768 unidades = 12:00
3.65V = 762 unidades = 12:15
3.63V = entre 759 y 758 = 12:30
3.61V = 754 unidades = 12:45
3.19V = 665 unidades = 19:39
2.41V = entre 506 y 501 = 20:23 (Bajon de intensidad de los leds evidente)

extra:  Justo cuando dejo de mandar datos vi como los led imediatamente se apagaron no se quedaron ensendidos como en otros casos 
y cuando trate de hacer una lectura de la vateria me marco 0V con el multimetro creo que esto es debido al circuito de proteccion
que contienen la baterias de polimero de litio entonces la carge solo 2segundos para que volviera a la vida y hice la medicion y me dio
un valor de 2.91V 

-------------------------------MEDICIONES SIN EL MULTIMETRO ----------------------------------------------------------------------------

Las sigueintes mediciones fueran las que nos dio la gracias cada 15min y en estos resultados utilizare la formula o la regla de tres 
que estaba utlizando para saber el valor de voltaje respecto de cada una de las unidades y de eso modo sabre si mi calculo esta bien
hecho en caso que no lo esto tratare de perfeccionarlo, normalmente utlizo la sigueinte igualdad 835 = 4.02V y hago la regla de tres. 

8-9-5-5-6

11:00 = 795 = 3.82V  
11:15 = 787 = 3.78V 
11:30 = 778 = 3.74V
11:45 = 773 = 3.72V  -
12:00 = 768 = 3.69V
12:15 = 762 = 3.66V
12:30 = 758 = 3.64V
12:45 = 754 = 3.63V
13:00 = 748 = 3.60V
13:15 = 744 = 3.58V
13:30 = 739 = 3.55V
13:45 = 734 = 3.53V
14:00 = 729 = 3.50V
14:15 = 726 = 3.49V
14:30 = 722 = 3.47V
14:45 = 720 = 3.46V
15:00 = 717 = 3.45V
15:15 = 716 = 3.44V
15:30 = 714 = 3.43V
15:45 = 712 = 3.42V
16:00 = 710 = 3.41V
16:15 = 709 = 3.41V
16:30 = 708 = 3.40V
16:45 = 706 = 3.39V
17:00 = 703 = 3.38V
17:15 = 702 = 3.37V
17:30 = 699 = 3.36V
17:45 = 694 = 3.34V
18:00 = 692 = 3.33V
18:15 = 689 = 3.31V
18:30 = 685 = 3.29V
18:45 = 680 = 3.27V
19:00 = 675 = 3.24V
19:15 = 673 = 3.24V
19:30 = 664 = 3.19V
19:45 = 660 = 3.17V
20:00 = 636 = 3.06V
20:15 = 589 = 2.83V
20:23 = 499 = 2.40V ULTIMO VALOR MEDIDO

ahora se comprararan las dos mediciones 
     Mediciones hechas con el multimetro         Mediciones calculadas      DIFERENCIA DE VOLTAJE
	3.77V = 787 unidades = 11:15 ------------ 11:15 = 787 = 3.7889V 		0.0189+
	3.73V = 778 unidades = 11:30 ------------ 11:30 = 778 = 3.7455V			0.0155+
	3.70V = 773 unidades = 11:45 ------------ 11:45 = 773 = 3.7215V			0.0215+
	3.67V = 768 unidades = 12:00 ------------ 12:00 = 768 = 3.6974V			0.0174+
	3.65V = 762 unidades = 12:15 ------------ 12:15 = 762 = 3.6685V			0.0185+
	3.63V = entre 759 y 758 = 12:30 --------- 12:30 = 758 = 3.6492V			0.0192+
	3.61V = 754 unidades = 12:45 ------------ 12:45 = 754 = 3.6300V			0.0200+
	3.19V = 665 unidades = 19:39 ------------ 19:39 = 665 = 3.2015V 		0.0115+
											0.0178125 Promedio

le saque la diverencia de cada uno para ver el margen de erro y como vi que 0.01 se repetia mucho tome mas decimales de los calculos
y lo promedie para poder sacar un valor un poco mas estable ahor hare los nuevos valores de voltaje utilizando la siguiente formula

((unidades que quiero convertir a voltaje)*4.02/835)-0.0178125
3.77109768       
3.727768338
3.703696482
3.679624626
3.650738398
3.631480913
3.612223428
3.183744386

con esta nueva formula se afinaron un poco mas los datos a los valores reales puesto que no cuento con un multimetro 
capas de leer muchos decimales se me es practicamente imporible poder tener mediciones mas finas puesto que no cuento con el equipo
necesario 

---------------------------CALCULOS DE CUANTO SE SUPONIDA QUE DURARIA ESTA PRUEBA CON EL VERDE-----------------------------------------

ahora lo que queremos hacer es determinar un valor teorico de cuanto se supondria que duraria la pulsera en funcionamiento como vimos en 
"Notas No. 5" el valor que dio la pila al medirla con el multimetro cuando se conecto fue de 3.64V y el de esta prueba fue de 3.87V
entonces supongamos que 3.64V es el 100% y determinemos el valor de 3.87V

3.64V = 100%
3.87V = ?

(3.87V*100%)/3.64V= 106.31% - 100% = 6.31% 

convertimos 6.31% a voltaje que es 0.23V

ahora lo convertimos a unidades 0.23V = 47 unidades aproximadamente

y unidades a tiempo utilizando los mismos calculos de las "Notas No. 5"
nos da que es equivalente a 1h con 10min y 30seg
------------------------------------CALCULO DE APROXIMACION DE TIEMPO ENCENDIDO DE PRUEBA NO.6-------------------------------------------

ahora teniendo en cuenta que cuando se hizo la prueba con losled amarillos duro 7h 12min y 58seg esto basado en las "Notas No. 5" y que 
segun la "Grafica de comparacion" en comparacion el led verde con el amarillo es la diferencia que tienen es de 1/3 o 33.33% convertire
estos valores a segundos y le sumare el 33.33% y despues le sumare el 6.31% que en si es 1h 10min 30seg

25979seg = 100%
    ?    = 133.33%

34638 seg = 9h 37min 18seg
esto mas el 6.31% que sacamos por que la pila estaba de mas cargada da 
10h 47min 30seg

----------------------------------CALCULOS CON EL VALOR RELA DEL TIEMPO QUE DURO LA PRUEBA------------------------------------------------

segun los calculos la prueba deberia de durar 10h 47min y 30seg pero el valor que de verdad duro fue 9h 23min y 52seg (5 min que no se 
prendieron los leds) que se asemeja muchisimo al valor que alculamos pero sin el 6.31% ahora sacaremos el margen de error respecto el 
margen de error fue de: 

38850seg = 100%
33832seg =  ?

esto nos da un margen de error de 12.91% 

---------------------------------------------Conclusiones--------------------------------------------------------------------------------

Un dato que fato remarcar es la MODA de la diferencia que hay entre las unidades despues de cada 15min y es de 5 unidades por lo cual esto
quiero decir que cada 15unidades tenemos un baja de 5 unidade a diferencia de la puega No. 5 se tuvo una MODA de 2,3 y 4 a continuacion 
muestro la tabla de diferencias 
8-9-5-5-6-4-4-6-4-5-5-5-3-4-2-3-1-2-2-2-1-1-2-3-1-3-5-2-3-4-5-5-2-9-4-24-47 existe 6(4), 8(5), 5(3), 7(2) y 4(1) se puede ver que los
valores mantienen una baja de entre 2 y 5 unidades que al parecer corresponde con que el valor del verde sea el 33.33% del amarillo

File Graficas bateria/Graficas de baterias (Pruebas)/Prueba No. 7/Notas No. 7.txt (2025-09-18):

Esta prueba fue corrida con el led rojo a 255 

En este caso a diferencia de lo que me salio en las "Notas No. 6" la bateria estuvo mas cargada por lo cual creo que esta vez durara un 
poco mas. La medicion que obtuve fue de 4.08V sin conectarlo a la pulsera una vez conectandolo tuve 3.95V y cuando empezo a mandar dato
bajo a 3.95V. 

------------------------------------------------VALORES DE CADA 15 MIN --------------------------------------------------------

A continuacion se muestran los valores medidos con un lapso de 15min 

Unidades      voltaje (teorico)         tiempo 

806		3.862570734V		04:25
800		3.833684506V		04:40
794		3.804798278V		04:55
786		3.766283308V		05:10
783		3.751840195V		05:25
776		3.718139596V		05:40
770		3.689253368V		05:55
765		3.665181512V		06:10
759		3.636295284V		06:25
754		3.612223428V		06:40
748		3.583337201V		06:55
745		3.568894087V		07:10
739		3.540007859V		07:25
735		3.520750374V		07:40
730		3.496678518V		07:55

En este punto se efectuo un apagon pero muy pequeño se puede ver en la grafica como un pequeño triangulo 
este apagon sucedio de las 08:05:27 a las 08:19:59 el tiempo que durante este apagon fue de 14 min con 32seg depues duro prendido durante
1min con 25seg y despues se volvio a apagar a las 08:20:34 y se prendio a las 08:20:53 osea que duro apagado durante 19seg y en total
duro apagado por 15min 51seg. Es por esta razon que las siguientes mediciones se les sumeraon 15min para hacer la medidicon mas exacta
independiendtemente del apago que ocurrio.

722		3.458163548V		08:35
722		3.458163548V		05:50
721		3.453349177V		09:05
718		3.438906063		09:20
717		3.434091692V		09:35
716		3.42927732V		09:50
712		3.410019835V		10:05
710		3.400391093V		10:20
712		3.410019835V		10:35
109		0.506953967V		10:50
708		3.39076235V		11:05
706		3.381133608V		11:20
703		3.366690494V		11:35
701		3.357061751V		11:50
696		3.332989895V		12:05
692		3.31373241V		12:20
687		3.289660554V		12:35
681		3.260774326V		12:55
680		3.255959955V		13:05
676		3.23670247V		13:20
670		3.207816243V		13:55
652		3.12115756V		13:50
607		2.904510853V		14:05
464		2.216055763V		14:17       (Ultima medicion)

NOTA IMPORTANTE: Puse una regla en la grafica para poder ver en que momento aproximadamente dejava de ser linear la caida de la carga
de la bateria y note que aproximadamente esta caida empezo en 674 al 660 que este valor en voltaje es igual a 3.227073728 y 3.15967253
despues promedie las diferencias de voltaje y de unidades y me dio en promedio cada 15min baja 4 unidades o 0.02V-

---------------------------CALCULOS DE CUANTO SE SUPONIDA QUE DURARIA ESTA PRUEBA CON EL ROJO-----------------------------------------

A continuacion realizare los debidos calculos para saber cuanto durara la pulsera prendida teoricamente y veremos cuanto no hacercamos 
al valor que queremos conseguir haciendo lo mismo que "Nota No. 6".

3.49V = 100%
3.95V = ?

dio 8.51% 

en voltaje 0.31487V
en unidades 65 
en tiempo 1h 37min 30seg

ahora teniendo en cuenta que cuando se hizo la prueba con losled amarillos duro 7h 12min y 58seg esto basado en las "Notas No. 5" y que 
segun la "Grafica de comparacion" en comparacion el led rojo con el amarillo es la diferencia que tienen es de 1/2 o 50% convertire
estos valores a segundos y le sumare el 50% y despues le sumare el 8.51% que en si es 1h 37min 30seg

25979seg = 100%
    ?    = 150% 

150% = 38,968.5seg = 10h 49min 28seg

ahora hay que sumerle el 8.15% que daria
12h 26min 58seg = 44,818seg

como en la anterior tuvimos un margen de error del 12.91% segun las "Noras No. 6" con estos datos ahora voy a sacar el 12.91% y luego 
lo restare para ver el valor teorisado 

100% = 44,818seg
12.91% = ?

12.91% = 5,786seg
5,786seg - 44,818seg = 39032seg = 10h 50min 32seg

----------------------------------------------------COMPARACION TIEMPO TEORICO CON EL REAL----------------------------------------------

el tiempo que duro la prueba fue de 10h 7min 21seg pero como hubo un apagon en un lapso de tiempo eso nos da que realmente fue de
9h 51min 30seg eso nos da un mergen de error del 

100% = 39032seg
  ?  = 35490seg
 
un hacierto del 90% el mas alto que he tenido hasta ahora 

aun que si contamos el tiempo que este duro sin prender (2min 38seg) los led el valor final se tiempo fuera  9h 54min 8seg

----------------------------------------------------CONCLUSIONES----------------------------------------------------------------------

cada vez que avanzan mas las pruebas se afina mucho mas las aproximaciones lo cual sera cricial para determinar cuanto puede durar la 
pulsera con los valores y las comparaciones hechas anteriormente. tambien cabe resaltar que todas las gracias parecen ser muy lineales
hasta un cierto punto necesitare graficas en otros programas para ver cual es este punto de caida pero al no contar con eso todavia 
lo dejare para pruebas posteriores en las pruebas del modo fiesta que sera la sigueinte pondre los valores y comparaciones de todos los
led se necesita hacer mas analisis para los datos para ver hacer suposisiones mas exactas.

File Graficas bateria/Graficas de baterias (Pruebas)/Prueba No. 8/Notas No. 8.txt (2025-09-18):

Esta prueba fue corrida con el MODO FIESTA a 255 y 50 milisegundos 

En esta prueba a diferencia de las anterirores vi que los valores fluctuaban mucho puesto que no pude hace un analisis de los datos tan
exactos como la anterior por lo cual me abstendre de hacer la prueba y ya que tenga la herramienta para graficar mejor le hare un 
analisis mas detallado al principi de la prueba isn conectar la pulsera la bateria me dio un valor al medir con el multimetro de 4.09V
y al conectarlo bajo a 3.94V y aqui fue cando ocurrio lo extraño puesto los valores empresaron fluctuar entre 3.91 y 3.88V, cuando volvi a
ver el proyecto ya se encontraba todo apagado y no logre ver ningun bajon de intensidad puesto que no lo estaba checando y cuando medi
con el multimetro em dio 0.60V y cuando desconecte la pulsera me dio 2.98V. como no tengo los otros datos solo realizare los calculos de la 
aproximacion de tiempo teorico y real, pero hay que tener en cuenta que no tomare este valor muy enserio puesto que no es una relacion
totalmente lineal y puede fluctuar demasiado 

--------------------------------------------------CALCULO TEORICO DE TIEMPO QUE DURARA LA PRUBEA-----------------------------------------

Se realizara el mismo procedimiento que las en "Notas 7" entonces teniendo en cuenta que 

3.49V = 100%
3.94V = ?

nos da 12.89%

3.70V = 100%
  ?   = 12.89%

nos da 0.47693V

que 1 unidad = 0.0048V
	 ?   = 0.47693V

nose da 99 unidades

10 unidades = 15min
99 unidades = ?

nos da 148.5min = 2h 28min 30seg

Ahora determinare cuanto tiempo durara respucto a el "Grafico de comparacion" a simple vista puedo notar que es un 60% aproximadamente
en comparacion a el led amarillo (duro 7h 12min y 58seg) entonces si es asi devemos de sumarle el 30% a lo que duro el led amarillo para ver cuanto duraria
teoricamente

25979seg = 100%
    ?    = 130% 

nos da 337723seg = 9h 22min 53seg

ahora hay que aumentar el 12.89% 

337723 + 8910 = 42683 seg = 11h 51min 23seg

como en la anterior tuvimos un margen de error del 12.91% segun las "Noras No. 6" con estos datos ahora voy a sacar el 12.91% y luego 
lo restare para ver el valor teorisado pero en "Notas No. 7" tuvomos 10% de marguen de error entonces sera un 22.92%

100%   = 42683seg
22.92% = ?

nos da 9783seg 

42683seg - 9783seg = 32900seg = 9h 8min 20seg

---------------------------------------------------COMPARACION CON VALORES REALES---------------------------------------------------------

el proyecto empezo a corer a las 11:12:46 y empezo con el modo fieta a las 11:15 eso son da una diferencia de 2min con 14seg, depues de eso
el timepo en el cual termino fue a las 20:42:34 esto nos da un tiempo de duracion del MODO FIESTA de 9h 27min 51seg ahora sacaremos el 
margen de error

entonces si el 

100% = 32900seg
  ?  = 34071seg

nos da un error del -3.5% osea que nos pasamos no como en los anteriores casos que nos faltaba, en esta ocacion solo nos equivocamos
por 1171seg o 19min y 31seg. 

-------------------------------------------------------CONCLUSIONES-----------------------------------------------------------------------

En esta prueba nos equivocamos por muy poco tiempo esto quiere decir que cada vez se esta afinaando el metodo y un error del 5% es tolerable
entonces pero no podemos poder esto como algo fiable puesto que este valor no es confiable por las fluctuaciones pero al menos es un buen
indicio que las cosas estan marchando correctamente. algo que tambien puedo notar es que a medida que pasa mas tiempo se produce mas ruido
en la señal puesto que es una señal que varia mucho y no tiene un falor fijo puesto que depende de la funcion random para que seleccione su
color. En esta prueba tambien hice lo de la ragla y tone que el valor donde empieza a desender de manera exponencial y que la grafica deja
de ser lineal es alrededor de los valores 660 al 650 unidades y tambien he notado o quiero especular que en muchas graficas se encuentra
una doble pendiente puesto cuando pongo la regla es diferente el la recta desde el primer punto de la prueba a aproximadamente la mitan
esta punto donde comeinza la otra pendiente es aproximado a el valor 730 es necesario checar las otrasgraficas y hacer un analisis para 
constatar que esto ocurre en todas las pruebas.

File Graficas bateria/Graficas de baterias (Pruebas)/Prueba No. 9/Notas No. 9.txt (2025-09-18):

Esta prueba fue corrida con todo apagago (TODO OFF)

en esta prueba se comprueba lo antes mencionado y apenas identificado en las "Notas No. 8" que es el echo que la grafica tiene dos pendientes
y al final una bajada exponencial, es esencial saber cuanto tiempo dura la pulsera con todas las funciones apagado en este caso solo se 
tuvo la funcion de madar datos puesto que con esto podemos identificar cuanto tiempo es el que se necesita para que se apague la pulsera
al medir con el multimetro sin conectar la pulsera nos dio un valor de 4.09V y cuando lo conecte a la pulsera dio 3.90V o 3.89V. Cuando
se descargo totalmente la bateria dio un voltaje de 0.60 conectado a la pulsera cuando lo desconecte me dio un voltaje de 3.04V

------------------------------------------------------------DATOS DE CADA 15 MIN----------------------------------------------------------

La prueba empeso a las 02:44:17 y termino a las 16:24:34

A continuacion se veran los resultados del muestreo de cada 15 min y la convercion utilizando la formula de "Notas No. 6" 
((unidades que quiero convertir a voltaje)*4.02/835)-0.0178125)

Timepo	     Unidades	          Voltaje
2:44:17		818		3.920343189V
2:59		802		3.843313249V
3:14		797		3.819241392V
3:29		794		3.804798278V
3:44		793		3.799983907V
3:59		785		3.761468937V
4:14		782		3.747025823V
4:29		777		3.722953967V
4:44		772		3.698882111V
4:59		769		3.684438997V
5:14		764		3.660367141V
5:29		760		3.641109656V
5:44		757		3.626666542V
5:59		754		3.612223428V
6:14		747		3.578522829V
6:29		746		3.573708458V
6:44		741		3.549636602V
6:59		739		3.540007859V
7:14		735		3.520750374V
7:29		732		3.50630726V
7:44		728		3.487049775V
7:59		725		3.472606662V
8:14		722		3.458163548V
8:29		721		3.453349177V
8:44		720		3.448534805V
8:59		717		3.434091692V
10:14		712		3.410019835V
10:29		710		3.400391093V
10:44		710		3.400391093V
10:59		709		3.395576722V
11:14		708		3.39076235V
11:29		706		3.381133608V
11:44		703		3.366690494V
11:59		705		3.376319237V
12:14		703		3.366690494V
12:29		702		3.361876123V
12:44		701		3.357061751V
12:59		696		3.332989895V
13:14		693		3.318546781V
13:29		691		3.308918039V
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
16:24:34 AM	536		2.562690494V

la moda en cuestion de unidades es de 3 unidades esto es la menor moda que he obtenido en las pruebas y de voltaje fue 0.01V teniendo
en cuenta solo las medicones de cada 15 min

ahora la primera pendiente cambia en el punto 08:07:10 = 722 unidades = 3.458163548V y la moda hasta este punto es 3 unidades = 0.01V
le primera pendiente es mas pronunciada que la segunda que es menor y esta pendiente ocurrio aproximadamente en el 41.5% de toda la prueba
la sgunda pendiente acabo en el punto 15:21:34 = 672 = 3.217444985V en este punto la moda fue mucho menor fue de 1 unidad = 0.005V
como se puede ver fue aproximadamente la mitad que la otra pendiente tanto en voltaje como en unidades se puede decir que aproximadamente
fue la mitad. Despues de la seugnda pendiente hubo una bajada de tipo exponencial la cual termino hasta el final de la prueba  esta caida 
duro un tiempo de 1h 3min.

--------------------------------------------------CALCULO TEORICO DE TIEMPO QUE DURARA LA PRUBEA-----------------------------------------

Se realizara el mismo procedimiento que las en "Notas 7" entonces 

3.49V = 100%
3.90V = ?

nos da 11.74%

3.70V = 100%
  ?   = 11.74%

nos da 0.434670V

1 unidad = 0.0048V
     ?   = 0.434970V

nos da 91 unidades

10 unidades = 15min
91 unidades = ?

136.5min = 8190seg = 2h 16min 30seg

Ahora determinare cuanto tiempo durara respucto a el "Grafico de comparacion" como estamos en el modo todo off seria el 100% de comparacion con el 
led amarillo que es con lo que se ha estado comprando 

25979seg = 100%
    ?    = 200% 

nos da 51958seg = 14h 25min 58seg

ahora hay que aumentar el 11.74%

51958seg + 8190seg = 60148seg = 16h 42min 28seg

como en la anterior tuvimos un margen de error del 12.91% segun las "Noras No. 6" con estos datos ahora voy a sacar el 12.91% y luego 
lo restare para ver el valor teorisado pero en "Notas No. 7" tuvomos 10% de marguen de error entonces sera un 22.92%

100%   = 60148seg
22.92% = ?

nos da 13786seg

60148 - 13786seg = 418,820seg = 46362seg = 12h 52min 42seg

---------------------------------------------------COMPARACION CON VALORES REALES---------------------------------------------------------

el tiempo real de la prueba fue de 13h 20min 17seg (48017seg) al comparar los valores anteriores vemos que existe una diferencias de 
28min con 25seg el cual es un valor muy cercano pero ahora vamos a ver el margen de error

100% = 46362seg
  ?  = 48017seg

nos da un margen de error de 3.56% y una diferencia de 1655seg el cual es un porcentaje muy bajo de error

----------------------------------------------------CONCLUSIONES----------------------------------------------------------------------

para la sigueinte prueba sera necesario sumar el margen de erroe que obtuvimos esta vez y seguir realizando las pruebas de las dos
pendeintes que se tienen en los casos de todas las graficas para ver si suceden en el mismo punto siempre como se vio la pulsera tiene
un gran tiempo de duracion mientras este no este mandando dato aun que vi algo raro puesto que no mandaba datos tan continuamente y la 
verdad nose por qeu sea en ciertos puntos mandaba un dato cada minuto y creo que esto fue devido a que la grafica se lleno y no puedo 
almacenar todos los datos por que cuando yo la checaba parecia funcionar correctamente.

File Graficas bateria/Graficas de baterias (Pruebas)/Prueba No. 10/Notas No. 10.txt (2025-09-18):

Esta prueba fue corrida con el MODO FIESTA a 255 y 250 milisegundos 

En esta prueba se comprueba lo antes mencionado y apenas identificado en las "Notas No. 8" que es el echo que la grafica tiene dos pendientes
y al final una bajada exponencial, es esencial saber cuanto tiempo dura la pulsera con todas las funciones apagado en este caso solo se 
tuvo la funcion de madar datos puesto que con esto podemos identificar cuanto tiempo es el que se necesita para que se apague la pulsera.
Tambien es necesatrio denotar que tube una pequeña desoneccion La prueba empezo a las cuando encendi el modo fiesta 00:9:49 y acabo a las
9:32:35 duro solo 33 segundos antes e empezar la prueba ocn los leds apagados

aproximadamente veo que la primer pendiente se termina en los puntos 735, 04:06:00 y noto que la segunda pendiente termina aproximadamente
en el punto 670 donde despues de eso empieza abajar exponencialmente. esta caida duro 38min se deberia de confirmar si es que en las otras
graficos se tiene una bajada similar

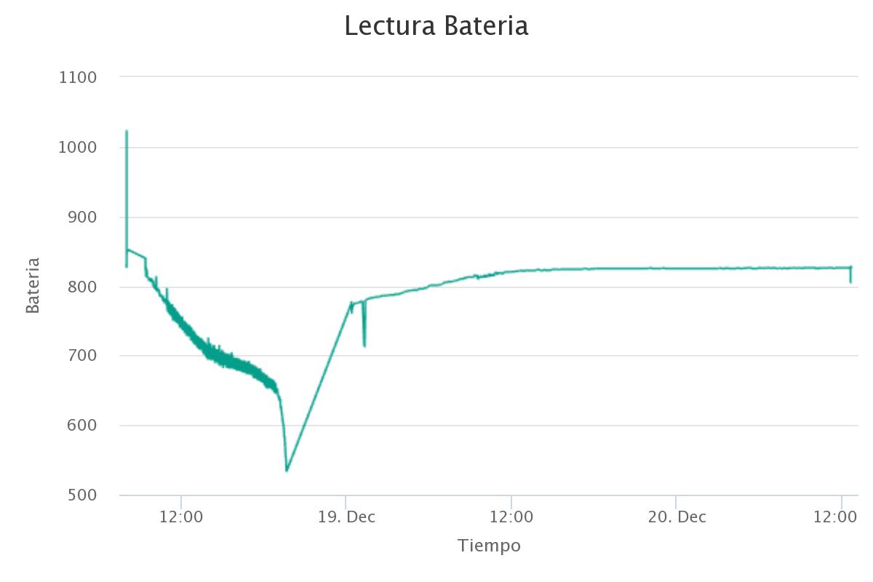
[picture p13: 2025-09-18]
Graficas bateria/Graficas de baterias (Pruebas)/Prueba No. 12/lectura-bateria (4).jpeg

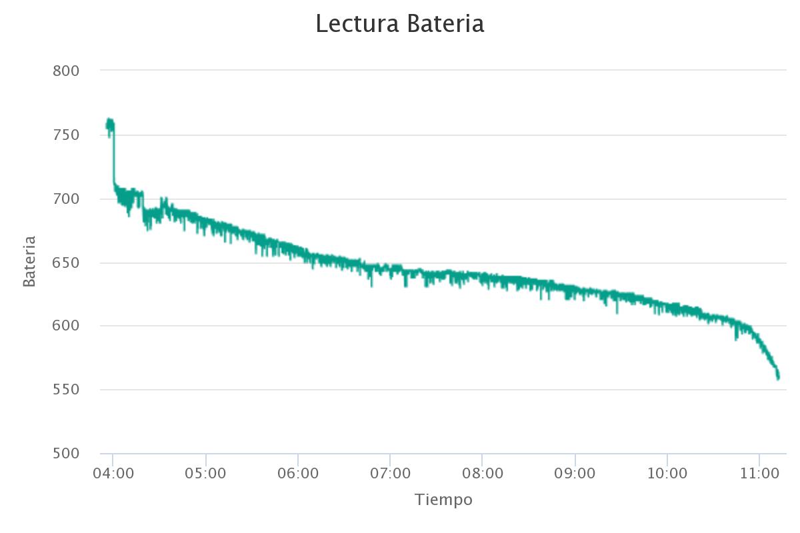
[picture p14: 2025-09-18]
Graficas bateria/Graficas de baterias (Pruebas)/Prueba No. 5/lectura-bateria.jpeg

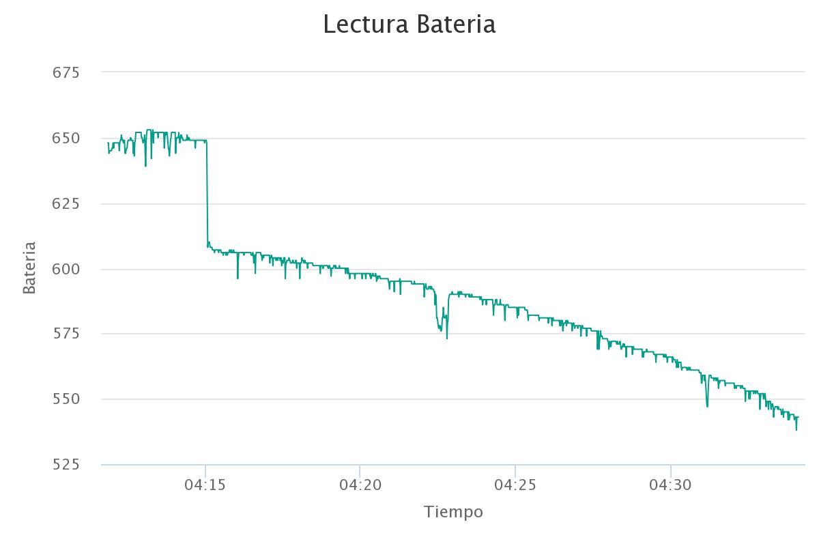
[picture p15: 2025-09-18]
Graficas bateria/Graficas de baterias (Pruebas)/Prueba No. 2/lectura-bateria.jpeg

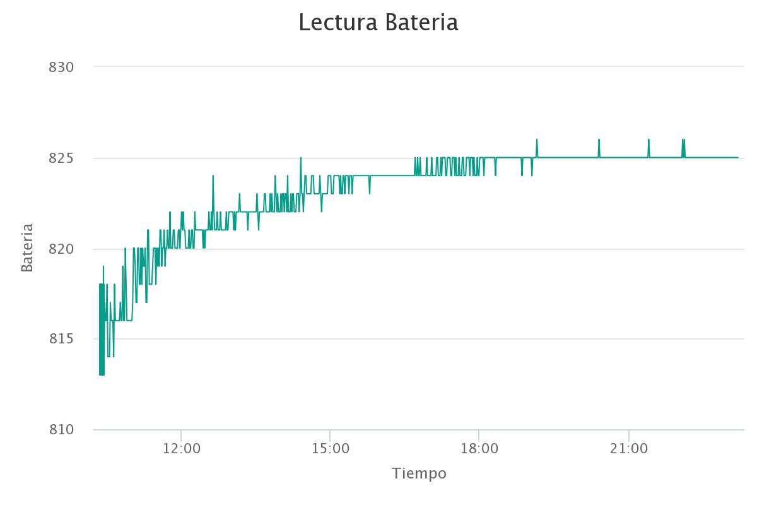
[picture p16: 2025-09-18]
Graficas bateria/Graficas de baterias (Pruebas)/Prueba No. 12/lectura-bateria (10).jpeg

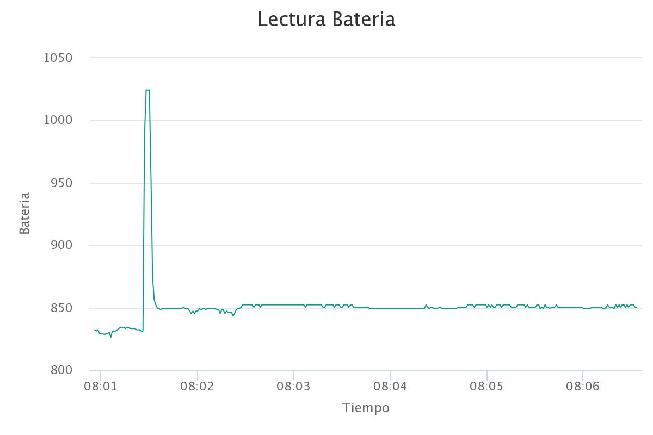
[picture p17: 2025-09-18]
Graficas bateria/Graficas de baterias (Pruebas)/Prueba No. 12/lectura-bateria.jpeg

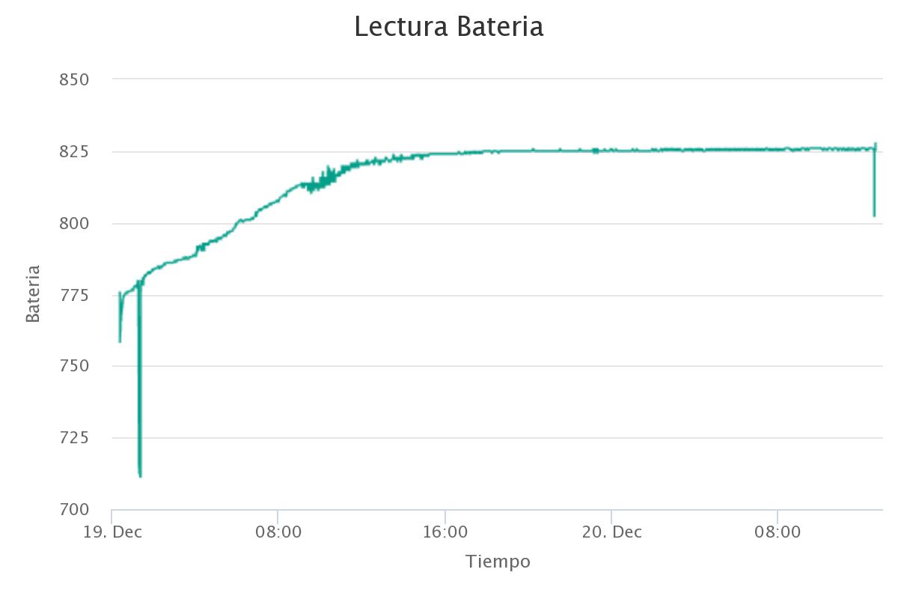
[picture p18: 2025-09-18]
Graficas bateria/Graficas de baterias (Pruebas)/Prueba No. 12/lectura-bateria (5).jpeg

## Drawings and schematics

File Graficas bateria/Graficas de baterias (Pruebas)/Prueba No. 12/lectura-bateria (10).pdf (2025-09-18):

## Lectura Bateria

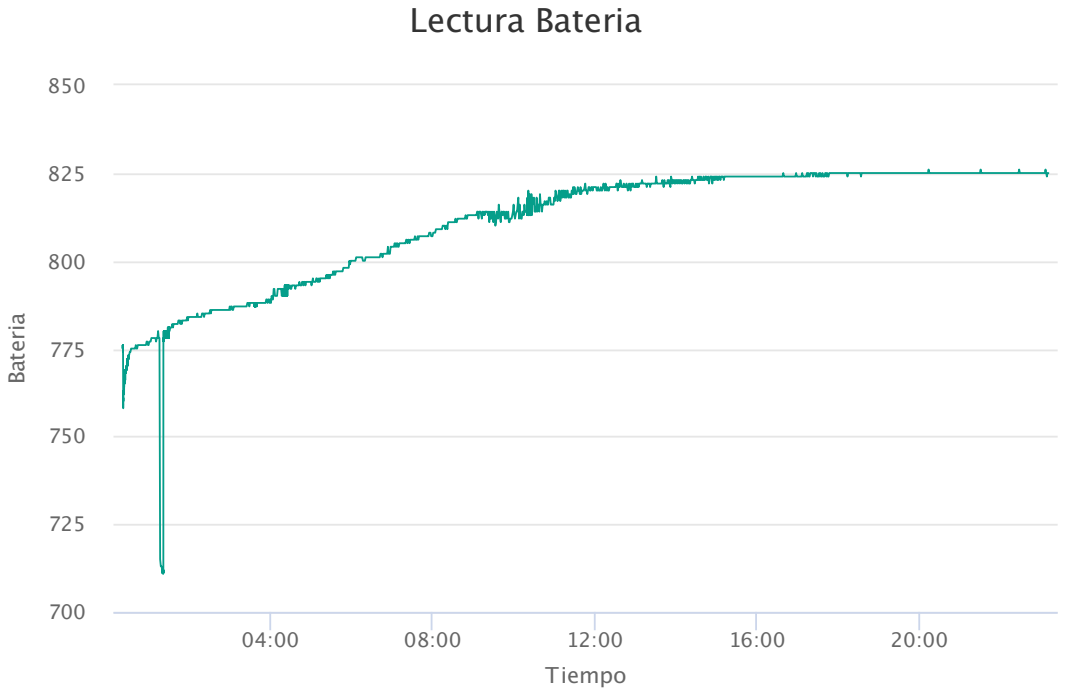
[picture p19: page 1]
Tiempo; ria

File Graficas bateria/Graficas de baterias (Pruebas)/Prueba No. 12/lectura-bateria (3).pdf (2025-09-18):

## Lectura Bateria

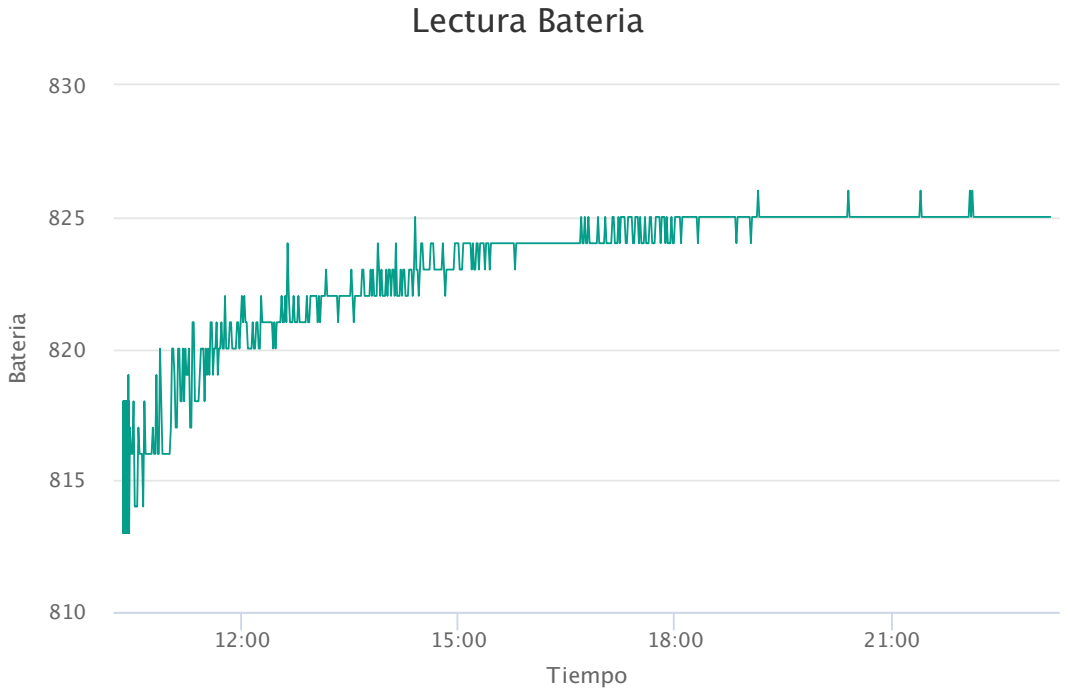
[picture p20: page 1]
Tiempo; ria

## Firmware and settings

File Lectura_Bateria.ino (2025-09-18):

#include <Arduino.h>
#include <ESP8266mDNS.h>
#include <ESP8266WiFi.h>
#include <Hash.h>
#include <ESPAsyncTCP.h>
#include <ESPAsyncWebServer.h>
#include <FS.h>
#include <FastLED.h>
/////////////////////////////////////////////////////////////////////////////////
// Actualización OTA
#include <WiFiUdp.h>
#include <ArduinoOTA.h>

//////////////////////////////////////////////////////////////////////////////////
#define NUM_LEDS 2      //Se define el numero de leds RGB que se utilizaran
#define DATA_PIN 5      //Se define el pin por el cual se trasmitiran los datos
CRGB leds[NUM_LEDS];    //se define la cantidad de leds con esta funcion

int Modo_Fiesta=0;      //Variable encargada de activar el modo fiesta en la pulsera

//WiFi 
const char* ssid = "Totalplay-19A2";          //SSID donde se conectara la pulsera
const char* password = "19A294AErC4fqSkj";    //Contraseña 

//variables del metodo GET los cuales tienen los niveles de intensidad
const char* intensidad_ledverde = "intensidadverde";
const char* intensidad_ledrojo = "intensidadrojo";
const char* intensidad_ledamarillo = "intensidadamarillo";
const char* intensidad_ledblanco = "intensidadblanco";
const char* intensidad_ledfiesta = "intensidadfiesta";
const char* tiempo_hibernacion = "tiempo";
const char* delay_fiesta = "delayfiesta";   //Esta variable contiene el tiempo del delay del modo fiesta

String inputMessage;             //Con este string leemos la variable que tiene el GET request
String inputParam;               //Con este string se lee el parametro de que tiene la variable en el GET request

//Variables de tipo entero donde se almacenara el valor de intensidad con que prendera cada comando
int nivel_intensidad_verde;
int nivel_intensidad_rojo;
int nivel_intensidad_amarillo;
int nivel_intensidad_blanco;
int nivel_intensidad_fiesta;
int nivel_tiempo_hibernacion;
int nivel_delay_fiesta;       //Entero que define el delay del modo fiesta

int deep_sleep=0;

//Crea un WebServer Asycrono en el puerto 80
AsyncWebServer server(80);

//Funcion encargada de la leectura de la vateria
String lectura_bateria() {
  float t = analogRead(A0);         //Realiza la leectura en el pinA0
    Serial.println(t);              //Imprime en el monitor serial el valor leido
    return String(t);               //devuelve el valor leido como un tring cuando es llamada la funcion
  
}


void setup(){
  //Inicializacion del puerto serial
  Serial.begin(115200);                                     //Puesto a 11520 bautios
  WiFi.mode(WIFI_STA);
  //Inicializa el led que viene en la placa 
  pinMode(LED_BUILTIN, OUTPUT);

  //Se define que tipo de leds RGB se estan usando, el pin por el cual se trasmitira el dato y el numero de leds
  FastLED.addLeds<WS2813, DATA_PIN, RGB>(leds, NUM_LEDS);
  
  bool status;

  //Inicializacion de la memoria interna SPIFFS
  if(!SPIFFS.begin()){
    Serial.println("An Error has occurred while mounting SPIFFS");    //Si no se puede inicializar mostrara este mensaje
    return;
  }

  //Conectando a el WiFi
  Serial.println("");
  Serial.println("");
  Serial.println("Estableciendo conexion WiFi");
  WiFi.begin(ssid, password);
  while (WiFi.status() != WL_CONNECTED) {
    delay(1000);
    Serial.print("...");
    digitalWrite(LED_BUILTIN, LOW);              //El led se enciende para indicar que no se ha conectado al WiFi
  }
//////////////////////////////////////////////////////////////////////////////////////////////////////////////
//  NOMBRE OTORGADO AL CHIP ESP8866
  ArduinoOTA.setHostname("Pufita_Pulsera");


ArduinoOTA.onStart([]() {
    String type;
    if (ArduinoOTA.getCommand() == U_FLASH) {
      type = "sketch";
    } else { // U_FS
      type = "filesystem";
    }

    // NOTE: if updating FS this would be the place to unmount FS using FS.end()
    Serial.println("Start updating " + type);
  });
  ArduinoOTA.onEnd([]() {
    Serial.println("\nEnd");
  });
  ArduinoOTA.onProgress([](unsigned int progress, unsigned int total) {
    Serial.printf("Progress: %u%%\r", (progress / (total / 100)));
  });
  ArduinoOTA.onError([](ota_error_t error) {
    Serial.printf("Error[%u]: ", error);
    if (error == OTA_AUTH_ERROR) {
      Serial.println("Auth Failed");
    } else if (error == OTA_BEGIN_ERROR) {
      Serial.println("Begin Failed");
    } else if (error == OTA_CONNECT_ERROR) {
      Serial.println("Connect Failed");
    } else if (error == OTA_RECEIVE_ERROR) {
      Serial.println("Receive Failed");
    } else if (error == OTA_END_ERROR) {
      Serial.println("End Failed");
    }
  });
  ArduinoOTA.begin();
 



//////////////////////////////////////////////////////////////////////////////////////////////////////////////
  //Imprime la IP local del ESP8266
  Serial.println("");
  Serial.print("La direccion IP es: ");
  Serial.println(WiFi.localIP());
  Serial.print("La direccion MAC es: ");
  Serial.println(WiFi.macAddress());
  //MDNS.begin("pulsera001");     //Inicializa el multiDNS y pone su direccion con pulsera001.local
  //MDNS.addService("http", "tcp", 80); //dice que el el metodo que utlizara "http" metodo de comunicacion "tcp" y el puerto "80"

  //Serial.println("La paguina web es: http://pulsera001.local");
  digitalWrite(LED_BUILTIN, HIGH);              //El led se apaga para indicar que la coneccion fue exitosa

  //Inicia la coneccion con el cliente (Navegador) y le manda el HTML que esta en la memoria SPIFFS
  server.on("/", HTTP_GET, [](AsyncWebServerRequest *request){
    request->send(SPIFFS, "/index.html");
  });

  //Manda el nivel de bateria leido por el ESP8266
  server.on("/battery", HTTP_GET, [](AsyncWebServerRequest *request){
    request->send_P(200, "text/plain", lectura_bateria().c_str());
  });

//ACCIONES DE LOS BOTONES


//ENCENDER BLANCO
  server.on("/ledblanco", HTTP_GET, [](AsyncWebServerRequest *request){   //Lee la primera parte del GET y verifica que contenga /ledblanco al inicio
        Serial.println("SE LEYO /ledblanco");                             //Manda un mensaje al monitor serial cuando se detecto el GET request
        if (request->hasParam(intensidad_ledblanco)) {                    //Revisa si existe una variable llamada "intensidadblanco" ya que intensidad_ledblanco="intensidadblanco"
        inputParam = request->getParam(intensidad_ledblanco)->value();    //Obtiene el valor que contiene la variable 
        inputMessage = intensidad_ledblanco;                              //Dice el nombre de la variable
        nivel_intensidad_blanco = inputParam.toInt();                     //Convercion a entero y se guarda en la variable de nivel_intensidad_blanco

        //Muestra la variable leida y su valor en el monitor serial
        Serial.print("Variable: ");
        Serial.println(inputMessage);
        Serial.print("Valor de la variable = ");
        Serial.println(inputParam);
        }
        Modo_Fiesta=0;          //Es necesario esta linea para que no inicie el modo fiesta si ya se habia iniciado con anterioridad
        leds[0] = CRGB(nivel_intensidad_blanco,nivel_intensidad_blanco,nivel_intensidad_blanco);    //se le pasa el valor de la intencidad que va de 0 a 255 y se declara en (Verde,Rojo,Azul)
        leds[1] = CRGB(nivel_intensidad_blanco,nivel_intensidad_blanco,nivel_intensidad_blanco);
        FastLED.show();         //Enciende los leds
        request->send(200, "text/plain");   //Manda un mensaje 200 diciendo que todo salio bien
    });

//MODO FIESTA
  server.on("/ledfiesta", HTTP_GET, [](AsyncWebServerRequest *request){
        Serial.println("SE LEYO EL MODO FIESTA!!");
        if (request->hasParam(intensidad_ledfiesta)) {
        inputParam = request->getParam(intensidad_ledfiesta)->value();
        inputMessage = intensidad_ledfiesta;
        nivel_intensidad_fiesta = inputParam.toInt();
        Serial.print("Variable: ");
        Serial.println(inputMessage);
        Serial.print("Valor de la variable = ");
        Serial.println(inputParam); 
        }
        if (request->hasParam(delay_fiesta)) {
        inputParam = request->getParam(delay_fiesta)->value();
        inputMessage = delay_fiesta;
        nivel_delay_fiesta = inputParam.toInt();
        Serial.print("Variable: ");
        Serial.println(inputMessage);
        Serial.print("Valor de la variable = ");
        Serial.println(inputParam); 
        }        
        Modo_Fiesta=1;                               //Inicia el modo fiesta declarado en el loop
        request->send(200, "text/plain");
    });

//MODO HIBERNAR
  server.on("/hibernar", HTTP_GET, [](AsyncWebServerRequest *request){
        Serial.println("SE LEYO /hibernar");
        if (request->hasParam(tiempo_hibernacion)) {
        inputParam = request->getParam(tiempo_hibernacion)->value();
        inputMessage = tiempo_hibernacion;
        nivel_tiempo_hibernacion = inputParam.toInt();
        Serial.print("Variable: ");
        Serial.println(inputMessage);
        Serial.print("Valor de la variable = ");
        Serial.println(nivel_tiempo_hibernacion); 
        }        
        Modo_Fiesta=0;                               //Inicia el modo fiesta declarado en el loop
        request->send(200, "text/plain");
        unsigned long previousMillis = 0;
        const long interval = nivel_tiempo_hibernacion;
        deep_sleep=1;
        Serial.println("Me voy a reiniciar");
        ESP.restart();
    });


//APAGAR TODO
  server.on("/led=todooff", HTTP_GET, [](AsyncWebServerRequest *request){
        Serial.println("SE LEYO led=todooff");
        Modo_Fiesta=0;
        leds[0] = CRGB(0,0,0);
        leds[1] = CRGB(0,0,0);
        FastLED.show();
        request->send(200, "text/plain");
    });
    
//DORMIR
server.on("/dormir", HTTP_GET, [](AsyncWebServerRequest *request){
        Serial.println("SE LEYO DORMIR");
        Serial.println("La pulsera se fue a dormir");
        Modo_Fiesta=0;
        request->send(200, "text/plain");
        ESP.deepSleep(0);
    });

//ENCENDER AMARILLO
    server.on("/ledamarillo", HTTP_GET, [](AsyncWebServerRequest *request){
        Serial.println("SE LEYO ledamarillo");
        if (request->hasParam(intensidad_ledamarillo)) {
        inputParam = request->getParam(intensidad_ledamarillo)->value();
        inputMessage = intensidad_ledamarillo;
        nivel_intensidad_amarillo = inputParam.toInt();
        Serial.print("Variable: ");
        Serial.println(inputMessage);
        Serial.print("Valor de la variable = ");
        Serial.println(inputParam);
        }
        Modo_Fiesta=0;
        leds[0] = CRGB(nivel_intensidad_amarillo,nivel_intensidad_amarillo,0);
        leds[1] = CRGB(nivel_intensidad_amarillo,nivel_intensidad_amarillo,0);
        FastLED.show();
        request->send(200, "text/plain");
    });

//ENCENDER ROJO
    server.on("/ledrojo", HTTP_GET, [](AsyncWebServerRequest *request){
        Serial.println("SE LEYO /ledrojo");
        if (request->hasParam(intensidad_ledrojo)) {
        inputParam = request->getParam(intensidad_ledrojo)->value();
        inputMessage = intensidad_ledrojo;
        nivel_intensidad_rojo = inputParam.toInt();
        Serial.print("Variable: ");
        Serial.println(inputMessage);
        Serial.print("Valor de la variable = ");
        Serial.println(inputParam);
        }
        Modo_Fiesta=0;
        leds[0] = CRGB(0,nivel_intensidad_rojo,0);
        leds[1] = CRGB(0,nivel_intensidad_rojo,0);
        FastLED.show();
        request->send(200, "text/plain");
    });

//ENCENDER VERDE 
    server.on("/ledverde", HTTP_GET, [](AsyncWebServerRequest *request){
        Serial.println("SE LEYO /ledverde");
        if (request->hasParam(intensidad_ledverde)) {
        inputParam = request->getParam(intensidad_ledverde)->value();
        inputMessage = intensidad_ledverde;
        nivel_intensidad_verde = inputParam.toInt();        
        Serial.print("Variable: ");
        Serial.println(inputMessage);
        Serial.print("Valor de la variable = ");
        Serial.println(inputParam);
        }
        Modo_Fiesta=0;
        leds[0] = CRGB(nivel_intensidad_verde,0,0);
        leds[1] = CRGB(nivel_intensidad_verde,0,0);
        FastLED.show();
        request->send(200, "text/plain");
    });

  //Inicia el Servidor 
  server.begin();
}
 
void loop(){  

  //MDNS.update(); //para que funcione el DNS 
  
  //Valores para hacer colores randoms
  int valor_1, valor_2, valor_3,valor_4, valor_5, valor_6;

  //Verifica el que el Modo fiesta halla sido ejecutado
  if(Modo_Fiesta==1){
    valor_1=random(nivel_intensidad_fiesta);   //Pone el nivel de intensidad como valor maximo donde el valor ira de 0 hasta el valor que tenga nivel_intensidad_fiesta que como maximo es 255
    valor_2=random(nivel_intensidad_fiesta);
    valor_3=random(nivel_intensidad_fiesta);
    valor_4=random(nivel_intensidad_fiesta);
    valor_5=random(nivel_intensidad_fiesta);
    valor_6=random(nivel_intensidad_fiesta);
    leds[0] = CRGB(valor_1,valor_2,valor_3);
    leds[1] = CRGB(valor_4,valor_5,valor_6);
    FastLED.show();
    delay(nivel_delay_fiesta);                //hace el cambio de colores en milisegundos dependiendo del lo que tenga la variable nivel_delay_fiesta en ella 
    }
  if(deep_sleep==1){
     ESP.deepSleep(nivel_tiempo_hibernacion*1000);
     delay(100);
    }  
///////////////////////////////////////////////////////////////////////////7
 // lOOPITA EL OTA MADRE
 ArduinoOTA.handle();
///////////////////////////////////////////////////////////////////////////////


    
}

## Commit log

2025-09-18 init: ESP web server + battery dashboard + CSV
2025-09-18 Añadi todos los archivos pertinentes los data sheets, graficos y pcb
    [BOM_Pulsera con GND_20190503220049.csv, BOM_wristband.xlsx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]
